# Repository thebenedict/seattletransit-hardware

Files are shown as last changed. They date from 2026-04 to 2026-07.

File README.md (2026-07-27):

# Seattle Transit Live

Schematic and PCB for a circuit board map of Seattle area public transit.

[www.seattletransitlive.com](https://www.seattletransitlive.com/)

This board uses an `ESP32-C3` to drive `383` individually addressable `WS2812` LEDs arranged as a stylized regional transit map. The LEDs are split across two chains, and represent live movement across rail, ferry, water taxi, and monorail routes.

## Main Functionality

- Displays a physical transit map with addressable LEDs placed along the network.
- Uses an `ESP32-C3-MINI-1` as the main controller.
- Takes power and USB data over `USB-C`.
- Drives the LED chains through level shifting and a switchable LED power rail.
- Includes an ambient light sensor for auto-dimming in software.

## Repo Contents

- `transit.kicad_sch`, `transit.kicad_pcb`, and the sub-sheet `.kicad_sch` files contain the Rev C schematic and PCB layout.
- `production/` contains fabrication outputs, BOM data, positions, and packaged manufacturing files.
- `tools/` contains scripts and transit GIS/GTFS inputs used to generate LED map configuration data.
- `3d_views/` and `web/public/` contain renders and SVG exports of the board.

## More soon

- Board firmware and supporting cloud service to be published separately.

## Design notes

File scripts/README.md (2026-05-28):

# Route Placement Scripts

## One-Line Route Placer

`place_route.py` places one line of WS2812B-2020 point LEDs along an existing
silkscreen route. On apply, it rewrites that silkscreen group with filleted
bends. It does not move WS2812B-MINI ferryport LEDs.

Draw the route as F.Silkscreen graphic line segments, group the segments for
one route, and name the group `route:<route_name>`, for example
`route:mukilteo_clinton`. A single straight route can be one grouped line
segment. For this first pass, draw source paths with line segments. After the
script fillets a group, reruns can still read the filleted line/arc pieces for
placement and will leave the existing filleted silk unchanged by default.

Routes can specify either explicit refs or a schematic sheet name:

```json
{
  "routes": {
    "mukilteo_clinton": {
      "silkscreen_group": "route:mukilteo_clinton",
      "schematic": "mukilteo_clinton"
    },
    "example_by_refs": {
      "silkscreen_group": "route:example_by_refs",
      "refs": "LED509-LED512"
    }
  }
}
```

When you pass `--route <route_name>` and that route is not present in the
config, `place_route.py` uses the same simple convention by default:
`silkscreen_group` becomes `route:<route_name>` and `schematic` becomes
`<route_name>`. This lets a config file act as defaults plus a few route
overrides.

When `schematic` is used, the script places all WS2812B-2020 point LED
footprints whose board sheet file or sheet name matches that value. MINI
ferryport LEDs in that schematic are skipped.

Run a dry run with KiCad's bundled Python:

```sh
/Applications/KiCad/KiCad.app/Contents/Frameworks/Python.framework/Versions/3.9/bin/python3.9 \
  scripts/place_route.py \
  --board transit.kicad_pcb \
  --config scripts/place_route.example.json \
  --route mukilteo_clinton
```

Add `--apply` to write the board. `silk_fillet_radius_mm` defaults to `4.0`;
set it per route or in `defaults`, or set it to `0` for sharp corners.
`silk_width_mm` defaults to `0.2`. Set `generate_silk: false` if you want a
route run to leave the grouped silkscreen untouched. If you intentionally want
to rewrite an already-filleted group, set `refillet_existing_silk: true`, but
the cleanest source remains straight segments. Use `reverse_path: true` when
the computed placement order is opposite the route direction you want, and
`reverse_refs: true` when the footprint order should run the other way along
the same path. For one-off runs, the same settings can be passed as
`--reverse-path` / `--no-reverse-path` and `--reverse-refs` /
`--no-reverse-refs`; CLI values override the config for the selected routes.

## Directional Two-Line Route Placer

`place_routes.py` places directional route LEDs and regenerates parallel route
silkscreen from construction lines drawn in KiCad.

## Station Decoration Generator

`stationgen` generates decorative station silkscreen from
`scripts/station_decorations.yaml`. It is intentionally scoped to generated
graphics: standard plain labels, rounded transfer rectangles, and terminal
knockout label pills. It does not move or own LED footprints.

Use the `Capture Selected Station to Config` KiCad IPC action to add stations
from selected LED footprints without typing reference designators. The visible
KiCad menu entry is a small legacy Action Plugin launcher that delegates to the
IPC implementation. See
`docs/stationgen.md` for the KiCad IPC plugin setup, capture workflow, and
config shape.

## Drawing Workflow

1. Use the `Route construction` layer.
2. Draw each route centerline with graphic line segments only. Bends are fine,
   but each segment should be a straight 0/45/90/etc. run. Do not draw arcs on
   the construction layer; the script rounds generated silkscreen bends.
3. Make the segment endpoints touch exactly. Snapping to endpoints/grid is
   recommended.
4. Select all construction segments for one route, group them, and set the
   group name to `route:<route_name>`, for example `route:fauntleroy_vashon`.
5. For a single straight route, duplicate the construction line in place, group
   the two collinear lines, and give that group the route name. The script
   merges overlapping collinear construction lines back into one segment.
6. Add a matching route entry to a JSON config file.

The construction centerline is the midpoint between the two generated
silkscreen lines. With the defaults, the generated silk lines are 4 mm apart,
the two directional LED lines are 4 mm apart, and sequential LED positions are
spaced 5 mm along straight route segments.

Construction endpoints are allowed to be ferry port LED anchors. Non-port ferry
LEDs and generated route silk use the coast-trimmed route path instead. Use
`coast_start_trim_mm` and `coast_end_trim_mm` when the construction line extends
past the coastline to reach a port LED.

## Config Shape

Use `routes.example.json` as a starting point. The simplest route looks like:

```json
{
  "routes": {
    "fauntleroy_vashon": {
      "construction_group": "route:fauntleroy_vashon",
      "refs": "LED526-LED529",
      "endpoints": {
        "start": { "ref": "LED525" },
        "end": { "ref": "LED508" }
      }
    }
  }
}
```

`refs` must be in wiring order. The first half of the refs are placed on the
first direction line from route start to route end. The second half are placed
on the opposite direction line from route end back to route start. This gives a
single data chain of all one-way ferry LEDs followed by all opposite-way ferry
LEDs, with one crossover at the far end. `refs` can be an explicit list, a
range string, or a list that mixes both:

```json
"refs": ["LED526", "LED527", "LED528", "LED529"]
"refs": "LED526-LED529"
"refs": ["LED526-LED529", "LED536", "LED537"]
```

Ranges are inclusive and can use `-` or `..`; `LED526-LED529` and
`LED526..LED529` are equivalent. Ranges can count up or down, so
`LED529-LED526` is valid.
The expanded ref count must be even. By default, the first direction line is on
the left side of the centerline, looking from the route start toward the route
end. Set `"first_direction_side": "right"` on a route to swap that.

`endpoints` can contain one endpoint. Use only `start` or only `end` when a
route reuses a port LED that is owned by another route.

Useful per-route overrides:

- `reverse`: default `true`; the script reverses the ordered construction
  polyline before placing anything. Set to `false` for a route whose
  construction traversal already runs from electrical start to electrical end.
- `coast_start_trim_mm` / `coast_end_trim_mm`: trim the construction path back
  to the coastline before placing non-port ferry LEDs or generating silk.
- `coast_clearance_mm`: default `0.0`; clearance from the coast-trimmed route
  ends to the first non-port ferry LED positions. Endpoint port LEDs ignore this
  and stay anchored to construction endpoints.
- `segment_clearance_mm`: default `0.0`; optional clearance at both ends of
  every straight construction segment. Use this only when you want extra spacing
  near bends as well as coasts.
- `merge_collinear_segments`: default `true`; overlapping or touching collinear
  construction lines are treated as one logical segment. Set to `false` when a
  special route needs to address those drawn subsegments by index.
- `led_spacing_along_mm`: default `5.0`.
- `line_spacing_across_mm`: default `4.0`.
- `silk_parallel_gap_mm`: default `4.0`.
- `silk_fillet_radius_mm`: default `4.0`; generated silkscreen bends are
  rounded to this radius when the adjacent segments are long enough.
- `silk_start_trim_mm` / `silk_end_trim_mm`: additionally shorten generated
  silk after coast trimming.
- `endpoint_orientation`: default `along_route`; ferry port endpoint LEDs are
  rotated to follow the endpoint route tangent. Use `perpendicular_to_route`
  only for an intentional exception.
- `endpoint_start_rotation_offset_deg`: default `-90.0`; compensates for the
  LED footprint at the start endpoint so its long visual edge follows the route.
- `endpoint_end_rotation_offset_deg`: default `0.0`; compensates for the LED
  footprint at the end endpoint so its long visual edge follows the route.
- `mirror_led_rotations_for_power`: default `true`; rotates one direction line
  by 180 degrees so the +VLED pads face the center power trunk.
- `led_rotation_offset_deg`: rotate route LEDs relative to the segment tangent.
- `strict_led_count`: default `true`; errors if geometry produces a different
  number of positions than the route has LEDs per direction. Set to `false` for
  best-effort placement: extra positions are ignored, and too few positions
  compress the route spacing so every ref still gets placed.

Per-segment overrides use zero-based segment indexes in the ordered route:

```json
"segments": {
  "0": { "start_clearance_mm": 2.0 },
  "1": { "no_leds": true },
  "2": { "led_count": 1, "center_offset_along_mm": -0.5 }
}
```

Per-LED overrides are the escape hatch for small visual fixes:

```json
"led_overrides": {
  "LED529": {
    "nudge_mm": [0.2, 0.0],
    "rotation_offset_deg": 180
  }
}
```

## Running

Run with KiCad's bundled Python:

```sh
/Applications/KiCad/KiCad.app/Contents/Frameworks/Python.framework/Versions/3.9/bin/python3.9 \
  scripts/place_routes.py \
  --board transit.kicad_pcb \
  --config scripts/routes.json
```

That is a dry run. It prints the ordered segments, computed route LED positions,
endpoint LED positions, and generated silkscreen count.

To write a copy:

```sh
/Applications/KiCad/KiCad.app/Contents/Frameworks/Python.framework/Versions/3.9/bin/python3.9 \
  scripts/place_routes.py \
  --board transit.kicad_pcb \
  --config scripts/routes.json \
  --apply \
  --output /tmp/transit-route-test.kicad_pcb
```

To regenerate only a route's generated silkscreen while leaving all LEDs and
reference visibility alone:

```sh
/Applications/KiCad/KiCad.app/Contents/Frameworks/Python.framework/Versions/3.9/bin/python3.9 \
  scripts/place_routes.py \
  --board transit.kicad_pcb \
  --config scripts/routes.json \
  --route mukilteo_clinton \
  --apply \
  --silk-only
```

To update the project board in place, close the PCB in KiCad first, then run:

```sh
/Applications/KiCad/KiCad.app/Contents/Frameworks/Python.framework/Versions/3.9/bin/python3.9 \
  scripts/place_routes.py \
  --board transit.kicad_pcb \
  --config scripts/routes.json \
  --apply
```

Generated silkscreen lines and fillet arcs are grouped as
`routegen:<route_name>`. Rerunning the script deletes and recreates that group,
so manual edits inside generated groups will not be preserved.

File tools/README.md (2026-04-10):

# LED Map Generation Pipeline

Generates `rev-a.json` (the board config) from KiCad source files and GTFS data.

## Required Input Files

### From KiCad project (you provide):
```
kicad/
├── transit.kicad_sch          # Main schematic (for reference)
├── rail_w.kicad_sch           # Rail West chain (106 LEDs, part 1)
├── rail_w_southbound.kicad_sch # Rail West chain (part 2, continues from rail_w)
├── rail_e.kicad_sch           # Rail East chain (48 LEDs)
├── ferries_n.kicad_sch        # Ferries North chain (46 LEDs)
├── ferries_s.kicad_sch        # Ferries South chain (47 LEDs)
└── transit.kicad_pcb          # PCB layout (for LED physical positions)
```

### From GTFS / transit agencies (downloaded):
- Sound Transit GTFS `stops.txt` and `shapes.txt`
- WSF terminal coordinates
- KC Water Taxi stop coordinates

### Hand-maintained:
- `station_labels.csv` — maps LED reference designators to station names and GTFS stop IDs

## Pipeline Steps

### Step 1: `01_extract_chain_order.py`
**Input:** KiCad `.kicad_sch` files (sub-sheets)
**Output:** `chain_order.json`

Parses schematic wiring to determine LED daisy-chain order per chain.
Traces DO→DI pin connections through wires.

```bash
python 01_extract_chain_order.py /path/to/kicad/
```

### Step 2: `02_extract_pcb_positions.py` (TODO)
**Input:** `transit.kicad_pcb`
**Output:** `pcb_positions.json`

Extracts board-space (x, y) position of every LED footprint from the PCB layout.

### Step 3: `03_merge_leds.py` (TODO)
**Input:** `chain_order.json` + `pcb_positions.json`
**Output:** `leds_merged.json`

Joins chain order with PCB positions. Assigns global indices. Validates 247 total.

### Step 4: `04_assign_stations.py` (TODO)
**Input:** `leds_merged.json` + `station_labels.csv` + GTFS data
**Output:** `leds_with_geo.json`

Enriches LEDs with station labels and geographic coordinates (lat/lng).

### Step 5: `05_build_routes.py` (TODO)
**Input:** `leds_with_geo.json` + GTFS shapes + route definitions
**Output:** `routes.json`

Constructs route objects with geoPath, ledIndices, ledProgress,
and progressThresholds. Handles shared LEDs across routes.

### Step 6: `06_assemble_rev_a.py` (TODO)
**Input:** `leds_with_geo.json` + `routes.json`
**Output:** `rev-a.json`

Assembles the final board config JSON with all sections.

### Step 7: `07_validate.py` (TODO)
**Input:** `rev-a.json`
**Output:** Validation report + visual overlay PNG

Comprehensive validation suite.

## Shared LED Handling

Three LEDs are shared across routes:

1. **Seattle water taxi terminal** — shared by Seattle–West Seattle WT and Seattle–Vashon WT
2. **First waypoint after Seattle terminal** — same two routes share their first leg
3. **Vashon triangle crossing** — Seattle–Vashon WT crosses Fauntleroy–Southworth WSF

These appear in multiple routes' `ledIndices` arrays but only once in the `leds` array.
Collision policy: last-writer-wins (active vessel takes priority).

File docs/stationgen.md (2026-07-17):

# StationGen

StationGen generates disposable silkscreen decoration for named stop groups.
LED footprints remain owned by the board and existing placement tools; StationGen
only owns generated graphics in groups named `stationgen:<station_id>`.

## Current Scope

- Transfer stations: rounded rectangle generated from the union of LED footprint
  bounding boxes, expanded by a style padding token. Rectangles may also use
  `decoration.angle_deg` for angled transfer groups.
- Standard stations: plain generated label text, with no station decoration.
- Ferry ports: plain generated label text, with no station decoration, using a
  larger label anchor radius for the WS2812B Mini footprint.
- Terminal stations: filled graphical-zone label pill plus knockout text. The
  zone fill is what lets KiCad's knockout text cut through the silkscreen fill.
- Labels: side-based placement around the station decoration/core with explicit
  `angle_deg`, `offset_mm`, alignment, and optional `position_mm` / `nudge_mm`
  exceptions.

No ferry-only terminal decoration is implemented yet.

## Config

The project config is [`scripts/station_decorations.yaml`](../scripts/station_decorations.yaml).
Styles define shared tokens; stations define intent:

```yaml
stations:
  intl_district_chinatown:
    class: standard
    refs: [LED1727, LED1827]
    label:
      text: |-
        Intl. District
        Chinatown
      align: left
      side: E

  mukilteo:
    class: transfer
    refs: [LED1101, LED1409, LED1421]
    label:
      text: Mukilteo
      align: auto
      side: NW
      offset_mm: 0.80

  vashon_island:
    class: ferry_port
    refs: [LED401]
    label:
      text: Vashon Island
      side: SW
      align: right
      align_x: right
      angle_deg: 45.0

  westlake:
    class: transfer
    refs: [LED1601, LED1733, LED1821]
    decoration:
      angle_deg: 315.0
```

Label positions use compass sides: `N`, `NE`, `E`, `SE`, `S`, `SW`, `W`,
`NW`, or `C`. `offset_mm` is projected clearance from the station geometry to
the rendered label geometry in that compass direction, so angled labels and
horizontal labels use the same spacing rule. Labels with `anchor_radius_mm`
configured and no generated decoration anchor against a style-controlled halo
around each selected LED center. This avoids rotated footprint bounding boxes
creating larger apparent gaps. Tune `anchor_radius_mm` on the applicable label
style if that station class needs to move in or out. Transfer labels anchor
against the generated rounded rectangle. Plain labels default to `align: auto`, which left-aligns
east-side labels, right-aligns west-side labels, and centers north/south labels
so text grows away from the station. Knockout pill labels default to centered
text.
Use YAML literal blocks for multiline labels; StationGen also normalizes KiCad
captured carriage returns to normal newline characters. Multiline generated text
defaults to KiCad `line_spacing: 1.0`; override `label.line_spacing` only when a
specific label needs tighter or looser leading.
Use `align_x: left|center|right` or `align_y: top|center|bottom` when a label
should keep a side placement but align one measured label edge with the station
decoration edge. For example, `side: N` plus `align_x: left` puts the label above
the station while aligning its left edge to the rectangle's left edge.
Use `cross_align: top|bottom|left|right|min|center|max` when the label should
stay on the requested side, but its centerline should align with a different
part of the station anchor along the cross axis. For example, `side: E` plus
`cross_align: top` keeps the label east of a diagonal LED pair while lining it
up with the upper LED instead of centering it between both LEDs.
For angled transfer boxes, set `decoration.angle_deg`; StationGen measures the
station content in that rotated coordinate system, applies the normal
`padding_mm`, and then generates a polygonal rounded rectangle on silkscreen.
Angled boxes use `decoration.content_radius_mm` as the visual radius around each
selected LED center before padding, which keeps diagonal groups from inheriting
oversized screen-aligned footprint bounding boxes. Labels for transfer stations
anchor against the generated rotated outline.

Stations can define internal `sublabels` for special cases like Seattle's
`Pier 50` and `Pier 52` labels. Sublabel text boxes are included in the
station's rounded-rectangle content box before normal decoration padding is
applied, and the sublabel text is generated inside the station group:

```yaml
stations:
  seattle:
    class: transfer
    refs: [LED701, LED515]
    sublabel_defaults:
      align: center
      vertical_align: center
      size_mm: 1.00
      stroke_mm: 0.15
    sublabels:
      - text: Pier 52
        position_mm: [125.77, 52.80]
      - text: Pier 50
        position_mm: [125.77, 60.80]
```

## KiCad Plugin

The repo-local plugin lives in [`stationgen`](../stationgen). This is an IPC API
plugin, not a legacy `pcbnew` action plugin, so it belongs in KiCad's versioned
`plugins` directory, not `scripting/plugins`:

```sh
mkdir -p /Users/michael/Documents/KiCad/10.0/plugins
rm -f /Users/michael/Documents/KiCad/10.0/plugins/stationgen
ln -s /Users/michael/Documents/transit/stationgen \
  /Users/michael/Documents/KiCad/10.0/plugins/stationgen
```

KiCad will create the plugin Python environment and install
[`stationgen/requirements.txt`](../stationgen/requirements.txt). KiCad's
visible PCB Editor menu still scans the legacy scripting plugin folder, so this
project also installs a small legacy Action Plugin launcher at:

```sh
/Users/michael/Documents/KiCad/10.0/scripting/plugins/stationgen_legacy_action_plugin.py
```

That launcher delegates to the IPC implementation. Use the PCB editor actions
under `Tools -> External Plugins`:

- `Regenerate Station Decorations`: delete and recreate generated decoration
  groups from the YAML config.
- `Capture Selected Station to Config`: create or update one station entry from
  the current selection.

On this Mac, these menu actions are also assigned as KiCad app shortcuts:

- `Cmd+Option+R`: `Regenerate Station Decorations`
- `Cmd+Option+C`: `Capture Selected Station to Config`

Make sure KiCad's IPC API is enabled first: KiCad -> Settings... -> Plugins ->
Enable KiCad API. Restart KiCad after adding the symlink. The action should then
appear in the PCB Editor as `Regenerate Station Decorations`; the first load may
take a little while while KiCad builds the plugin Python environment. If the
menu only shows `Refresh Plugins` and `Reveal Plugin Folder in Finder`, click
`Refresh Plugins`. That menu's reveal command opens
`/Users/michael/Documents/KiCad/10.0/scripting/plugins`, not the IPC plugin
folder.

If KiCad creates the plugin environment but does not show the action in the UI,
leave the board open and run StationGen directly through the KiCad-created
environment:

```sh
cd /Users/michael/Documents/transit
/Users/michael/Library/Caches/KiCad/10.0/python-environments/com.charlesstreetlabs.stationgen/bin/python \
  -m stationgen --config scripts/station_decorations.yaml
```

To add another station without typing LED reference designators, select the
station's LED footprints in the PCB editor. Optionally select one existing free
text label too; StationGen will use it as the default label text, label angle,
and side hint. Plain selected text defaults to the `standard` class; knockout
selected text defaults to `terminal`; selecting only footprints defaults to
`transfer`. Then run `Capture Selected Station to Config`. The dialog lets you
choose the station id, `standard`, `ferry_port`, `transfer`, or `terminal`, side
placement, text alignment, optional edge/cross alignment, and whether to
regenerate that station immediately. After a successful capture, StationGen
removes the selected source text label from the board so the generated label is
the only copy.

The same capture workflow can run from the terminal while the board is open:

```sh
cd /Users/michael/Documents/transit
/Users/michael/Library/Caches/KiCad/10.0/python-environments/com.charlesstreetlabs.stationgen/bin/python \
  -m stationgen \
  --config scripts/station_decorations.yaml \
  --capture-selected
```

For a non-dialog capture, pass the needed options explicitly:

```sh
/Users/michael/Library/Caches/KiCad/10.0/python-environments/com.charlesstreetlabs.stationgen/bin/python \
  -m stationgen \
  --config scripts/station_decorations.yaml \
  --capture-selected \
  --capture-no-dialog \
  --station-id northgate \
  --station-class transfer \
  --label-text Northgate \
  --label-side E \
  --label-align auto \
  --label-cross-align top \
  --regenerate-after-capture
```

Terminal knockout labels trigger a KiCad zone refill. If KiCad remains busy
longer than the IPC wait loop, StationGen may print a warning but the refill can
still finish in KiCad; wait for the board to become responsive before saving.

Do not create a `stationgen` symlink inside the repo's own
`/Users/michael/Documents/transit/stationgen` directory. KiCad 10.0.1 traverses
plugin folders recursively during startup, and a recursive symlink can crash
KiCad during plugin discovery.

StationGen only deletes and recreates groups with the configured generated
prefix. Existing hand-drawn silkscreen labels and rectangles are left alone, so
delete or move those manually as stations are migrated into the YAML config.

For command-line config validation:

```sh
python -m pip install -r stationgen/requirements.txt
python -m stationgen --config scripts/station_decorations.yaml --check-config
```

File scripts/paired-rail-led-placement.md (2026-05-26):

# Paired Rail LED Placement

This note describes the manual PCB transform used for the Sounder and Tacoma
paired LED rails. It is scriptable because each partner footprint is derived
from its already-placed mate with a fixed geometric rule.

## Inputs

- KiCad board file: `transit.kicad_pcb`
- Sheet path, for example `/Rail/sounder_s/`, `/Rail/sounder_n/`, or
  `/Rail/tacoma_t/`
- First group refs in track order, for example `LED1501` through `LED1512`
- Partner group refs in matching order, for example `LED1513` through
  `LED1524`
- Pair spacing: `4.0 mm`

The schematic should already contain the correct sequential electrical chain
for both groups. If the partner refs are out of order, fix the refs/net chain
first, then apply the geometry transform.

## PCB Parsing

Parse `transit.kicad_pcb` as balanced S-expressions, not line-by-line text.
For this task it is enough to split top-level `(footprint ...)` forms while
respecting quoted strings.

Select only footprints with:

```scheme
(sheetname "/Rail/<sheet_name>/")
```

Then read:

- reference from `(property "Reference" "LED1501" ...)`
- symbol path from `(path ".../<symbol_uuid>")`
- top-level footprint placement from the first footprint-level `(at x y rot)`
- pad nets from pads whose `pinfunction` is `DI_3` or `DO_1`

## Pair Geometry

For each pair:

```text
source_ref  = LED1501 + i
partner_ref = LED1513 + i
```

Read the source footprint center and rotation:

```text
x, y, theta_deg
```

Compute the partner center using the same 4 mm normal offset convention used on
the board:

```text
dx = 4.0 * cos(theta_deg)
dy = -4.0 * sin(theta_deg)

partner_x = x + dx
partner_y = y + dy
partner_rotation = theta_deg + 180
```

Normalize rotation only for presentation if desired. KiCad accepts equivalent
angles such as `-45`, `315`, or `135`; consistency matters more than the exact
range.

Examples:

```text
theta -45  -> offset (+2.828427, +2.828427), partner rotation 135
theta -90  -> offset (0, +4), partner rotation 90
theta -135 -> offset (-2.828427, +2.828427), partner rotation 45
theta 180  -> offset (-4, 0), partner rotation 0
```

This puts the partner footprint on the parallel silkscreen rail and rotates it
to face the opposite travel direction.

## PCB Rewrite

For every partner footprint:

1. Replace the top-level footprint `(at x y rot)` with the computed partner
   placement.
2. Update nested `(at local_x local_y rot)` rotations inside that same
   footprint to the computed partner rotation. This includes reference/value
   fields, user text, and pads.
3. Do not change the footprint UUID, schematic path, reference, pad nets, or
   any unrelated footprint.

The source group footprints are read-only inputs for this operation.

## Sequential Ref Repair

If geometry is correct but partner refs run out of order, derive the actual
chain from the PCB nets:

1. Build a map from each partner footprint's `DI_3` net to its reference.
2. For each partner footprint, map its `DO_1` net to the next footprint whose
   `DI_3` uses that net.
3. Walk from the first partner ref whose `DI_3` is unconnected or externally
   sourced.
4. Rename that walked order to the desired sequential refs.

When applying a ref permutation, use temporary placeholders so names do not
collide:

```text
LED1328 -> __TMP_01__ -> LED1326
```

Apply the same ref permutation to:

- schematic symbol `Reference` properties
- schematic instance references
- PCB footprint `Reference` properties
- PCB net names such as `Net-(LED1328-DO)`
- unconnected net names such as `unconnected-(LED1328-DI-Pad3)`

After renaming, keep symbol UUID/path associations intact. If moving logical
footprints to different physical slots, transplant only the `(at ...)` values
from the destination slot to the logical footprint.

## Validation

After rewriting the PCB, verify all of these before opening KiCad:

1. Every expected source and partner ref exists exactly once on the target
   sheet.
2. For each pair:

   ```text
   hypot(partner_x - source_x, partner_y - source_y) == 4.000000
   (partner_rotation - source_rotation) mod 360 == 180
   ```

3. The partner chain is sequential:

   ```text
   LED1513 -> LED1514 -> ... -> LED1524
   ```

   Derive this from `DO_1` to `DI_3` nets, not from footprint order in the file.

4. PCB footprint paths still match schematic symbol UUIDs for the sheet.
5. Run:

   ```sh
   git diff --check -- transit.kicad_pcb
   ```

## Minimal Script Shape

A future script can expose this as:

```sh
python scripts/place_paired_rail_leds.py \
  --board transit.kicad_pcb \
  --sheet /Rail/tacoma_t/ \
  --source LED1501-LED1512 \
  --partners LED1513-LED1524 \
  --spacing-mm 4.0 \
  --apply
```

The script should default to a dry run that prints the computed placements and
the validation table before writing the board.

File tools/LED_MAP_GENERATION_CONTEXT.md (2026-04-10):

# Transit Tracker — LED Map Generation: Context & Instructions

This document provides full context for generating `led-maps/rev-a.json`, the board configuration file that maps real-world geographic coordinates to LED indices on a physical transit display board.

Read this document fully before starting work.

## Project Summary

The Transit Tracker is a physical PCB with 247 individually addressable WS2812B LEDs arranged on a stylized transit map of the Puget Sound region. A cloud service polls transit APIs for real-time vehicle positions (lat/lng), maps each position to the nearest LED, and streams color updates to the board over SSE.

The full design document is at `transit-tracker-design.md`. Read it for the SSE protocol, firmware architecture, and web frontend details — but for this task, only the LED map JSON schema (§6) matters.

## The Core Problem

The board's map is **stylized** (like a subway diagram), not geographic. There is no affine transform from lat/lng to board space. We need a data file that lets the server answer: "A vehicle is at lat/lng X on route Y — which LED do I light up?" in effectively constant time.

## The Solution: Route-Progress Based Lookup

Each route is modeled as a progress bar from 0.0 to 1.0 along its real-world geographic polyline:

1. Server receives vehicle position (lat/lng) + route ID + direction from API
2. Project lat/lng onto the route's real-world geoPath polyline → scalar progress (0.0–1.0)
3. Find nearest value in `ledProgress` → LED index

The polyline projection uses standard point-to-polyline snapping: for each segment of the polyline, compute the perpendicular projection, clamp to segment bounds, find the nearest segment, and compute progress as cumulative distance to that point divided by total polyline length. At Puget Sound latitudes (~47.5°N), use a local Cartesian approximation (scale longitude by cos(47.5°)) — Earth curvature error is negligible at city scale.

For the runtime server (Node.js), Turf.js `nearestPointOnLine()` does this in one call. For offline generation (Python), Shapely `line.project(point, normalized=True)` does it.

## Ferry vs Rail: Direction Handling

**Ferry routes** use a single line of LEDs for both directions. A ferry at the midpoint of a crossing lights the same LED regardless of heading. The server ignores direction — it just projects lat/lng onto the route's geoPath. One route object per ferry route.

**Rail routes** have separate LED strips per direction (northbound LEDs are physically different from southbound LEDs on the board). The server uses the trip direction from the API to select the correct route object. Two route objects per rail line (one per direction). Both geoPath polylines follow the same physical track, just in opposite directions.

## Input Data

### 1. Transit_stops__LEDs.csv (in project root)

**This is the primary data source.** A manually created file mapping every LED to its route(s), chain position, and station label. 307 rows, 9 columns:

- **Type**: "Light rail", "Ferry", "Monorail", "Taxi"
- **Chain**: "Rail W", "Rail E", "Ferries N", "Ferries S"  
- **REF**: LED reference designator, e.g. "LED201"
- **Route**: Route identifier — "1" (Line 1), "2" (Line 2), "sea-br" (Seattle-Bremerton), "sea-bi" (Seattle-Bainbridge), "ed-king" (Edmonds-Kingston), "pd-tal" (Point Defiance-Tahlequah), "s-v" (Southworth-Vashon), "f-s" (Fauntleroy-Southworth), "f-v-s" (Fauntleroy-Vashon-Southworth triangle), "taxi-vashon" (Seattle-Vashon water taxi), "taxi-west-seattle" (Seattle-West Seattle water taxi), "monorail"
- **Direction**: "Northbound", "Southbound", "Eastbound", "Westbound", or empty (ferries)
- **Order in route**: 0-indexed position within that route
- **Order in chain**: 0-indexed position within the physical LED chain
- **Label**: Station/terminal name (empty for waypoint LEDs between stations)
- **Note**: Annotations about shared LEDs, skipped designators, etc.

Key structural patterns:
- Station LEDs and waypoint LEDs alternate: every other LED has a label
- LEDs appearing in multiple rows are **shared LEDs** (same physical LED, multiple routes)
- Rail W chain (106 LEDs): LED201-LED253 (northbound) + LED601-LED653 (southbound, separate sub-sheet)
- Rail E chain (48 LEDs): LED301-LED348
- Ferries N chain (46 LEDs): LED401-LED447 (LED430 was skipped due to schematic error)
- Ferries S chain (47 LEDs): LED501-LED547

### 2. GIS Route Polylines (in gis-data/)

These provide the real-world geographic paths for each route:

- **`gis-data/wsdot-ferry-routes.geojson`** — WSF ferry route polylines from WSDOT GIS portal. GeoJSON LineString features with route name attributes. Covers all WSF routes (sea-br, sea-bi, ed-king, pd-tal, s-v, f-s, f-v-s).

- **`gis-data/sound-transit-gtfs/`** — Unzipped Sound Transit GTFS (from `https://www.soundtransit.org/GTFS-rail/40_gtfs.zip`). Contains `shapes.txt` (route polylines), `stops.txt` (station lat/lng), `routes.txt`, `trips.txt`. Covers Link Lines 1 and 2.

- **`gis-data/kcm-gtfs/`** — Unzipped King County Metro GTFS (from `https://www.soundtransit.org/GTFS-KCM/google_transit.zip`). Contains water taxi route shapes and stops. Covers taxi-vashon and taxi-west-seattle.

- **`gis-data/monorail-gtfs/`** — Unzipped Seattle Monorail GTFS (from `https://gtfs.sound.obaweb.org/prod/96_gtfs.zip`). Covers the monorail route.

### 3. Ferry_Routes.geojson (in project root)

May contain the same or similar ferry route data as the WSDOT download. Check and use if present.

## Shared LEDs

These physical LEDs appear in multiple routes. They appear as multiple rows in the CSV with the same REF but different Route values:

1. **LED513** (Southworth) — routes `s-v` and `f-s`
2. **LED525** (Fauntleroy) — routes `f-s` and `f-v-s`  
3. **LED508** (Vashon Island) — routes `s-v`, `f-v-s`, and `taxi-vashon`
4. **LED518** — crossing point where `taxi-vashon` crosses `f-s` (noted "Crosses f-s, shared LED")
5. **LED543** — shared by `taxi-vashon` and `taxi-west-seattle` (Seattle terminal area)
6. **LED601–LED627** on Rail W — shared by Line 1 southbound and Line 2 eastbound (the downtown overlap section, Lynnwood to Intl District)
7. **LED227–LED253** on Rail W — shared by Line 1 northbound and Line 2 westbound

Collision policy: last-writer-wins. When two vehicles on different routes map to the same LED, the most recently processed one determines the color. No blending needed.

## Output: rev-a.json Schema

```jsonc
{
  "boardRevision": "A",
  "totalLeds": 247,
  
  "chains": {
    "rail_w":    { "gpio": 10, "count": 106 },
    "rail_e":    { "gpio": 1,  "count": 48 },
    "ferries_n": { "gpio": 5,  "count": 46 },
    "ferries_s": { "gpio": 4,  "count": 47 }
  },

  "gpios": {
    "vled_en":      { "gpio": 6, "active_high": true },
    "lvl_shift_en": { "gpio": 7, "active_high": false },
    "wifi_led":     { "gpio": 0, "active_high": true }
  },

  "leds": [
    {
      "index": 0,                    // global LED index (0..246)
      "chain": "rail_w",             // which physical chain
      "chainIndex": 0,               // position within chain (0-indexed)
      "ref": "LED201",               // schematic reference designator
      "label": "Federal Way Downtown", // station name, or null for waypoints
      "type": "station",             // "station" | "terminal" | "waypoint"
      "package": "2020"              // "2020" (WS2812B-2020) or "mini" (WS2812B-MINI)
    }
    // ... 247 entries total
  ],

  "routes": [
    {
      "id": "link-1-northbound",
      "type": "rail",                // "rail" | "ferry" | "monorail" | "water_taxi"
      "operator": "sound_transit",
      "line": "1",                   // matches Route column in CSV
      "direction": "northbound",     // null for ferries
      "defaultColor": { "r": 0, "g": 200, "b": 0 },

      // Ordered LED indices for this route (references into leds[])
      "ledIndices": [0, 1, 2, ...],

      // Real-world route polyline (from GTFS/GIS)
      "geoPath": [[47.3174, -122.3032], [47.3180, -122.3030], ...],

      // Progress value (0.0-1.0) along geoPath for each LED
      // Same length as ledIndices
      "ledProgress": [0.0, 0.019, 0.038, ...]
    }
  ],

  "sharedLeds": [
    {
      "ledIndex": 42,               // global index
      "ref": "LED513",
      "routes": ["southworth-vashon", "fauntleroy-southworth"],
      "note": "Southworth terminal"
    }
  ],

  "collisionPolicy": "last_writer_wins"
}
```

### Important notes about the schema:

- `leds[].index` is the global index (0-246). The mapping from global index to chain is deterministic: rail_w = 0..105, rail_e = 106..153, ferries_n = 154..199, ferries_s = 200..246. The `chainIndex` field gives the position within the chain.

- `leds[]` does not contain geographic coordinates. All geographic data lives in `routes[].geoPath` and `routes[].ledProgress`. The leds array is purely about physical board identity (chain, index, ref, label, package).

- `routes[].geoPath` is `[lat, lng]` pairs (not `[lng, lat]` — match the GTFS convention).

- `routes[].ledIndices` references global LED indices, not chain indices. A route can span chains (Line 2 spans rail_w and rail_e).

- `routes[].ledProgress` — for station LEDs, computed by projecting the GTFS stop coordinate onto the route's geoPath. For waypoint LEDs (unlabeled, between stations), interpolated evenly between the flanking stations' progress values.

- At runtime, the server finds the nearest LED by binary-searching `ledProgress` for the vehicle's progress value, then comparing the two neighboring entries to find the closest. No precomputed thresholds needed.

- Ferry routes have `"direction": null`. Rail routes always have a direction.

- The `package` field: the 13 ferry terminal LEDs use "mini" (WS2812B-MINI, larger package). All others use "2020". The terminals are the labeled endpoints of ferry routes (Seattle, Bainbridge Island, Bremerton, Kingston, Edmonds, Fauntleroy, Vashon Island, Southworth, Point Defiance, Tahlequah, West Seattle) plus the two water taxi Seattle terminals. Determine which are "mini" from the CSV labels at chain endpoints.

## What to Build

A Python script (or small set of scripts) that:

1. **Parses the CSV** to extract chain order, route definitions, station labels, and shared LED relationships.

2. **Reads GIS data** (GeoJSON for ferries, GTFS shapes.txt/stops.txt for rail/monorail/water taxi) to get route polylines and station coordinates.

3. **Matches stations to GTFS stops** — the CSV `Label` values need to be matched to GTFS `stop_name` values to get lat/lng. This may require fuzzy matching (e.g., "SeaTac / Airport" vs "SeaTac/Airport Station"). Log any unmatched stations for manual review.

4. **Builds geoPath for each route** — for rail, extract the GTFS shape polyline for the correct route+direction. For ferries, extract the matching route from the ferry GeoJSON. For routes spanning multiple chains (Line 2), concatenate the geoPath segments.

5. **Computes ledProgress** — project each station LED's GTFS stop coordinate onto its route's geoPath to get its progress value. Interpolate waypoint LEDs evenly between flanking stations.

6. **Assembles and writes rev-a.json** — combining all the above into the schema described.

7. **Validates** — check LED count (247), chain sizes (106, 48, 46, 47), route continuity, progress monotonicity, geographic plausibility (station lat/lng from GTFS within Puget Sound bounding box ~47.0-48.0 lat, -123.0 to -122.0 lng).

### Handling GTFS shapes.txt

GTFS `shapes.txt` format:
```
shape_id,shape_pt_lat,shape_pt_lon,shape_pt_sequence,shape_dist_traveled
```

To find the right shape_id for a given route+direction:
1. In `routes.txt`, find the `route_id` for the line (filter by `route_short_name` or `route_long_name`)
2. In `trips.txt`, find trips for that `route_id` with the desired `direction_id` (0 or 1)
3. Get the `shape_id` from those trips
4. In `shapes.txt`, collect all points for that shape_id, ordered by sequence
5. Convert to a GeoJSON LineString or list of [lat, lng] pairs

### Handling ferry GeoJSON

The WSDOT ferry routes GeoJSON has features with route identification in their properties (likely a `ROUTE_ID` or `ROUTENAME` field). Inspect the file to determine the exact property name, then filter features by route. Each feature's geometry is a LineString of [lng, lat] coordinates (GeoJSON standard is [lng, lat], so swap to [lat, lng] for our schema).

### Route ID Mapping

Map the CSV `Route` values to the GIS data source identifiers:

| CSV Route | Type | GIS Source | Notes |
|---|---|---|---|
| 1 | rail | Sound Transit GTFS | Line 1, both directions |
| 2 | rail | Sound Transit GTFS | Line 2, both directions |
| sea-br | ferry | WSDOT GeoJSON | Seattle-Bremerton |
| sea-bi | ferry | WSDOT GeoJSON | Seattle-Bainbridge |
| ed-king | ferry | WSDOT GeoJSON | Edmonds-Kingston |
| pd-tal | ferry | WSDOT GeoJSON | Point Defiance-Tahlequah |
| s-v | ferry | WSDOT GeoJSON | Southworth-Vashon |
| f-s | ferry | WSDOT GeoJSON | Fauntleroy-Southworth |
| f-v-s | ferry | WSDOT GeoJSON | Fauntleroy-Vashon (triangle leg) |
| taxi-vashon | water_taxi | KCM GTFS | Seattle-Vashon water taxi |
| taxi-west-seattle | water_taxi | KCM GTFS | Seattle-West Seattle water taxi |
| monorail | monorail | Monorail GTFS | Westlake-Seattle Center |

### Color Defaults

| Route type | Color |
|---|---|
| Line 1 | Green: (0, 200, 0) |
| Line 2 | Blue: (0, 80, 255) |
| WSF ferries | White: (255, 255, 255) |
| Water taxis | Turquoise: (0, 220, 200) |
| Monorail | Red: (255, 0, 0) |

## Working Notes

- The CSV has 307 rows but only 247 unique LEDs — the extra rows are shared LEDs appearing in multiple routes.
- LED430 was skipped in the schematic (noted in CSV). The chain goes LED429 → LED431. This doesn't affect anything — just means there's no LED with ref "LED430".
- The `Order in chain` column in the CSV directly gives the `chainIndex` value for each LED.
- The `Order in route` column gives the position within the route's `ledIndices` array.
- For Line 2, the route spans two chains: it starts on Rail W (shared LEDs) then continues on Rail E (or vice versa depending on direction). The `ledIndices` array will contain global indices from both chains.

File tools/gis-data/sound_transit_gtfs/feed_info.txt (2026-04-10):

feed_id,feed_publisher_name,feed_publisher_url,feed_lang,feed_start_date,feed_end_date,feed_version,default_lang,feed_contact_email,feed_contact_url
40,Sound Transit,https://www.soundtransit.org,en,20260202,20260828,SC-Spring-2026.4,en,open_transit_data@soundtransit.org,https://www.soundtransit.org/help-contacts/business-information/open-transit-data-otd

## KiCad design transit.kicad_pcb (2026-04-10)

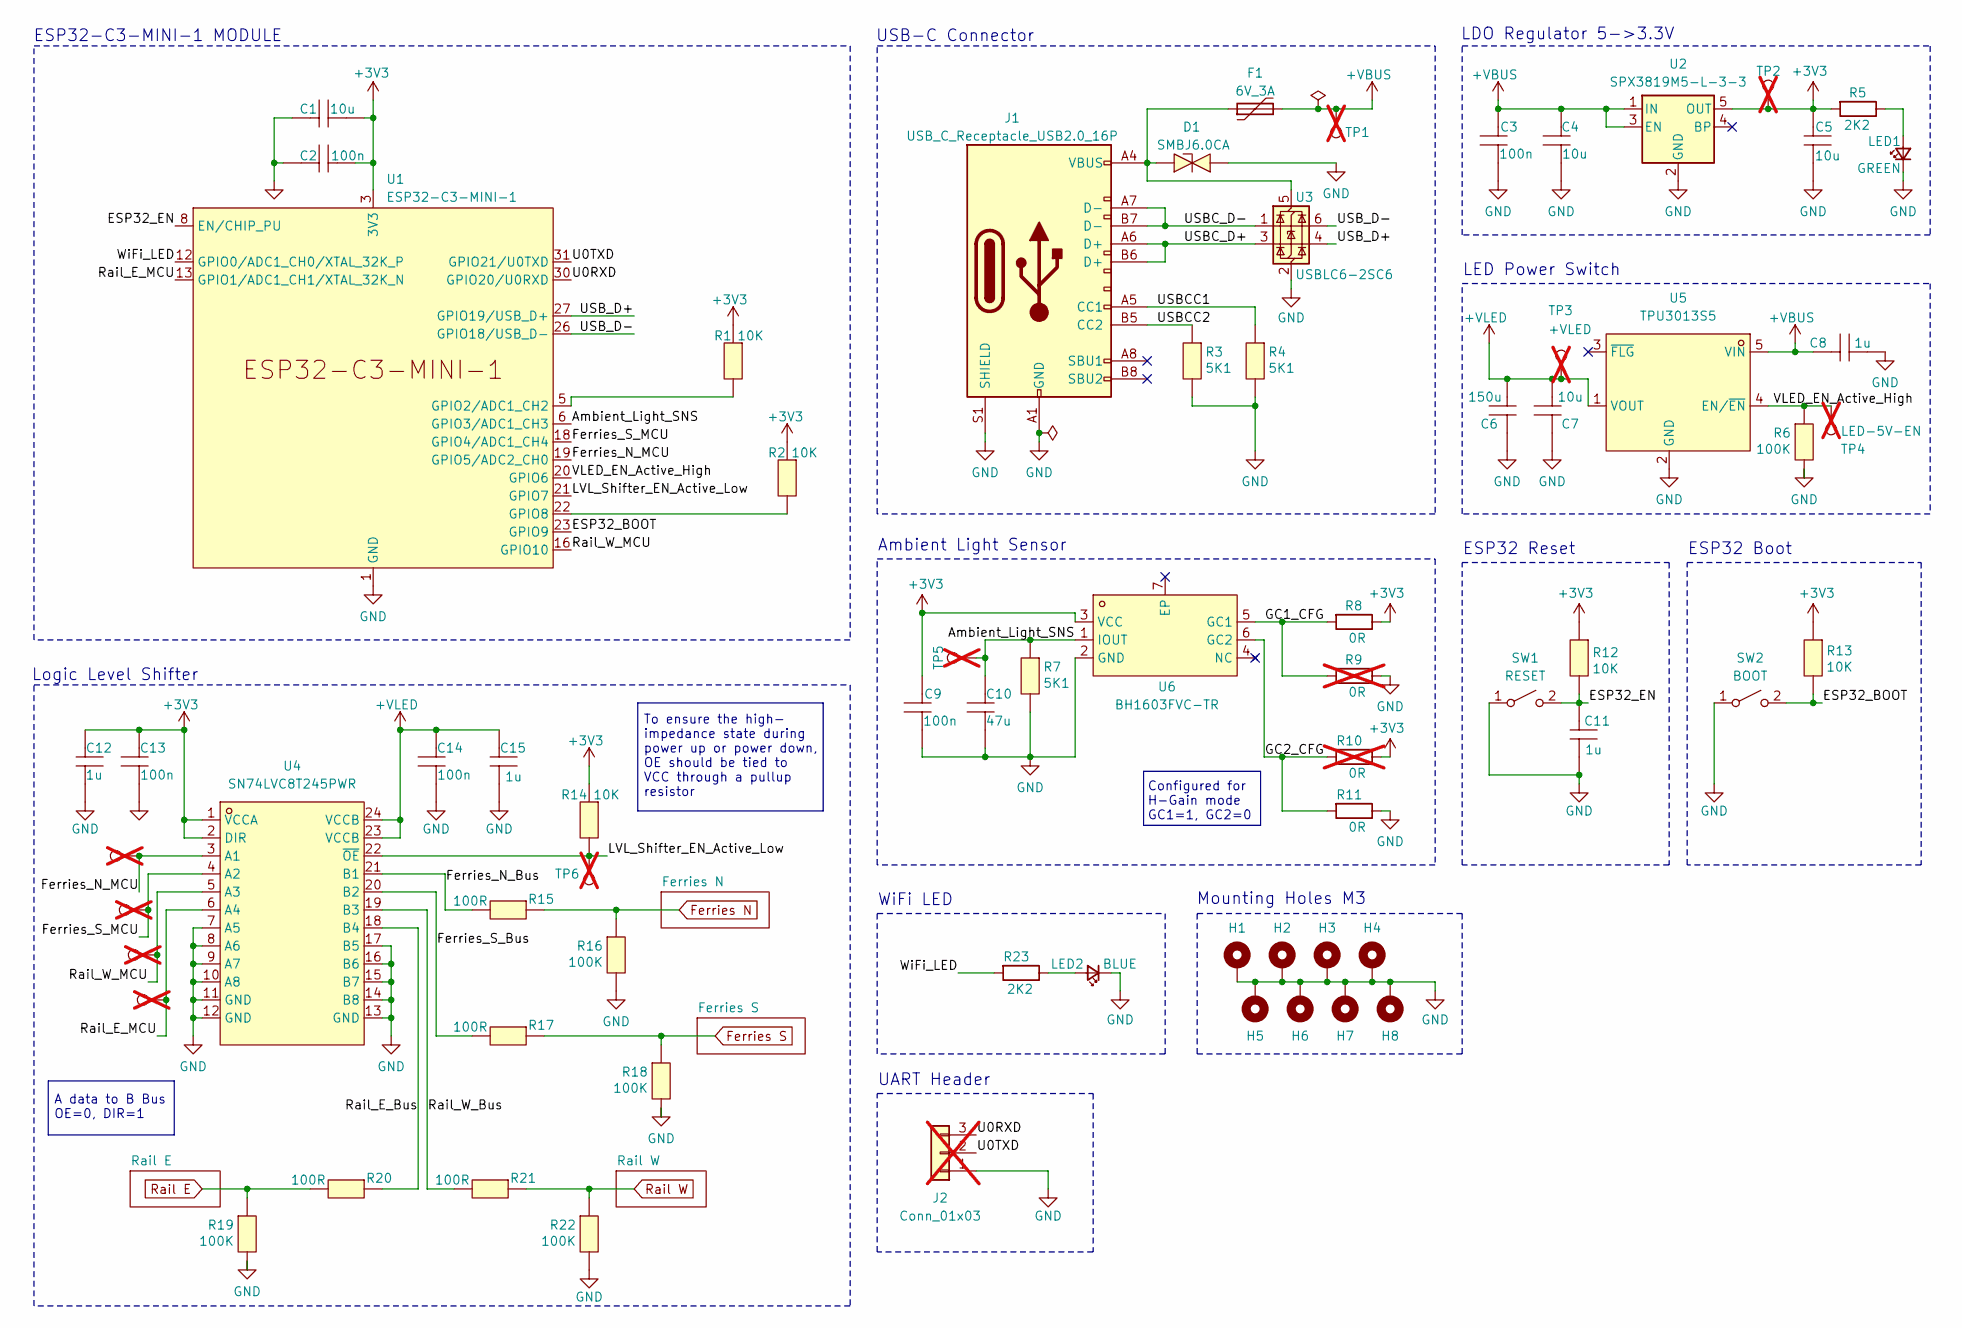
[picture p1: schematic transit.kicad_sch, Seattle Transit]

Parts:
C1, C4, C5, C7: 10u; C0805; LCSC Part C95841
C2, C3, C9, C13, C14: 100n; C0603; LCSC Part C1591
C6: 150u; CAP-SMD_L3.5-W2.8; LCSC Part C212682
C8, C11, C12, C15: 1u; C0603; LCSC Part C15849
C10: 47u; C1206; LCSC Part C96123
D1: SMBJ6.0CA; SMB_L4.3-W3.6-LS5.4-BI; LCSC Part C78812
F1: 6V_3A; F1210; LCSC Part C914223
H1, H2, H3, H4, H5, H6, H7, H8: MountingHole_3.2mm_M3_DIN965_Pad
J1: USB_C_Receptacle_USB2.0_16P; USB_C_Receptacle_GCT_USB4105-xx-A_16P_TopMnt_Horizontal; LCSC C393939
J2: Conn_01x03; PinHeader_1x03_P2.54mm_Vertical; not fitted
LED1: GREEN; LED0805-R-RD; LCSC Part C2297
LED2: BLUE; LED0805-R-RD; LCSC Part C2293
R1, R2, R12, R13, R14: 10K; R0603; LCSC Part C25804
R3, R4, R7: 5K1; R0603; LCSC Part C23186
R5, R23: 2K2; R0603; LCSC C4190
R6, R16, R18, R19, R22: 100K; R0603; LCSC Part C25803
R8, R11: 0R; R0603; LCSC C21189
R9, R10: 0R; R0603; LCSC C21189; not fitted
R15, R17, R20, R21: 100R; R0603; LCSC Part C22775
SW1, SW2: SW_SPST; KEY-SMD_L6.2-W3.6-LS8.0_K2-1107ST-A4SW-06; LCSC Part C118141
TP1: +VBUS; TestPoint_Keystone_5005-5009_Compact; not fitted
TP2: +3V3; TestPoint_Keystone_5005-5009_Compact; not fitted
TP3: +VLED; TestPoint_Keystone_5005-5009_Compact; not fitted
TP4: LED-5V-EN; TestPoint_Keystone_5005-5009_Compact; not fitted
TP5: Ambient-Light-SNS; TestPoint_Keystone_5005-5009_Compact; not fitted
TP6: LVL-Shifter-EN; TestPoint_Keystone_5005-5009_Compact; not fitted
TP7: Ferries-S-MCU; TestPoint_Keystone_5005-5009_Compact; not fitted
TP8: Ferries-N-MCU; TestPoint_Keystone_5005-5009_Compact; not fitted
TP9: Rail-W-MCU; TestPoint_Keystone_5005-5009_Compact; not fitted
TP10: Rail-E-MCU; TestPoint_Keystone_5005-5009_Compact; not fitted
U1: ESP32-C3-MINI-1; LCSC C2838502
U2: SPX3819M5-L-3-3; SOT-23-5_L3.0-W1.6-P0.95-LS2.8-BR; LCSC Part C20617301
U3: USBLC6-2SC6; SOT-23-6_L2.9-W1.6-P0.95-LS2.8-BL; LCSC C7519
U4: SN74LVC8T245PWR; TSSOP-24_L7.8-W4.4-P0.65-LS6.4-BL; LCSC Part C27643
U5: TPU3013S5; SOT-23-5_L2.9-W1.6-P0.95-LS2.8-BR; LCSC Part C46472316
U6: BH1603FVC-TR; WSOF-6_L2.6-W1.6-P0.50-BL-EP; LCSC Part C132180

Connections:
+3V3: C1.2, C2.2, C5.1, C9.2, C12.1, C13.2, R1.1, R2.1, R5.2, R8.1, R10.1, R12.1, R13.1, R14.1, TP2.1, U1.3 (3V3), U2.5 (OUT), U4.1 (VCCA), U4.2 (DIR), U6.3 (VCC)
+VBUS: C3.2, C4.1, C8.1, F1.2, TP1.1, U2.1 (IN), U2.3 (EN), U5.5 (VIN)
+VLED: C6.1, C7.1, C14.2, C15.1, TP3.1, U4.23 (VCCB), U4.24 (VCCB), U5.1 (VOUT); also elsewhere on the board
/Ambient_Light_SNS: C10.2, R7.1, TP5.1, U1.6 (GPIO3/ADC1_CH3), U6.1 (IOUT)
/ESP32_BOOT: R13.2, SW2.2 (B), U1.23 (GPIO9)
/ESP32_EN: C11.1, R12.2, SW1.2 (B), U1.8 (EN/CHIP_PU)
/Ferries_N_Bus: R15.2, U4.21 (B1)
/Ferries_N_MCU: TP7.1, U1.19 (GPIO5/ADC2_CH0), U4.3 (A1)
/Ferries_S_Bus: R17.2, U4.20 (B2)
/Ferries_S_MCU: TP8.1, U1.18 (GPIO4/ADC1_CH4), U4.4 (A2)
/GC1_CFG: R8.2, R9.2, U6.5 (GC1)
/GC2_CFG: R10.2, R11.2, U6.6 (GC2)
/LVL_Shifter_EN_Active_Low: R14.2, TP6.1, U1.21 (GPIO7), U4.22 (~OE)
/Rail_E_Bus: R20.1, U4.18 (B4)
/Rail_E_MCU: TP10.1, U1.13 (GPIO1/ADC1_CH1/XTAL_32K_N), U4.6 (A4)
/Rail_W_Bus: R21.2, U4.19 (B3)
/Rail_W_MCU: TP9.1, U1.16 (GPIO10), U4.5 (A3)
/U0RXD: J2.3, U1.30 (GPIO20/U0RXD)
/U0TXD: J2.2, U1.31 (GPIO21/U0TXD)
/USBCC1: J1.A5 (CC1), R4.1
/USBCC2: J1.B5 (CC2), R3.1
/USBC_D+: J1.A6 (D+), J1.B6 (D+), U3.3 (I/O2)
/USBC_D-: J1.A7 (D-), J1.B7 (D-), U3.1 (I/O1)
/USB_D+: U1.27 (GPIO19/USB_D+), U3.4 (I/O2)
/USB_D-: U1.26 (GPIO18/USB_D-), U3.6 (I/O1)
/VLED_EN_Active_High: R6.1, TP4.1, U1.20 (GPIO6), U5.4 (EN/~EN)
/WiFi_LED: R23.2, U1.12 (GPIO0/ADC1_CH0/XTAL_32K_P)
Ferries N: R15.1, R16.1; also elsewhere on the board
Ferries S: R17.1, R18.1; also elsewhere on the board
GND: C1.1, C2.1, C3.1, C4.2, C5.2, C6.2, C7.2, C8.2, C9.1, C10.1, C11.2, C12.2, C13.1, C14.1, C15.2, D1.1, H1.1, H2.1, H3.1, H4.1, H5.1, H6.1, H7.1, H8.1, J1.A1 (GND), J1.A12 (GND), J1.B1 (GND), J1.B12 (GND), J1.S1 (SHIELD), J2.1, LED1.1 (K), LED2.1 (K), R3.2, R4.2, R6.2, R7.2, R9.1, R11.1, R16.2, R18.2, R19.2, R22.2, SW1.1 (A), SW2.1 (A), U1.1 (GND), U1.2 (GND), U1.11 (GND), U1.14 (GND), U1.36 (GND), U1.37 (GND), U1.38 (GND), U1.39 (GND), U1.40 (GND), U1.41 (GND), U1.42 (GND), U1.43 (GND), U1.44 (GND), U1.45 (GND), U1.46 (GND), U1.47 (GND), U1.48 (GND), U1.49 (GND), U1.50 (GND), U1.51 (GND), U1.52 (GND), U1.53 (GND), U2.2 (GND), U3.2 (GND), U4.7 (A5), U4.8 (A6), U4.9 (A7), U4.10 (A8), U4.11 (GND), U4.12 (GND), U4.13 (GND), U4.14 (B8), U4.15 (B7), U4.16 (B6), U4.17 (B5), U5.2 (GND), U6.2 (GND); also elsewhere on the board
unnamed: LED1.2 (A), R5.1
unnamed: LED2.2 (A), R23.1
unnamed: R1.2, U1.5 (GPIO2/ADC1_CH2)
unnamed: R2.2, U1.22 (GPIO8)
unnamed: D1.2, F1.1, J1.A4 (VBUS), J1.A9 (VBUS), J1.B4 (VBUS), J1.B9 (VBUS), U3.5 (VBUS)
Rail E: R19.1, R20.2; also elsewhere on the board
Rail W: R21.1, R22.1; also elsewhere on the board

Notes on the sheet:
Configured for H-Gain mode GC1=1, GC2=0
Ambient Light Sensor
A data to B Bus OE=0, DIR=1
Mounting Holes M3
LDO Regulator 5->3.3V
LED Power Switch
Logic Level Shifter
To ensure the high- impedance state during power up or power down, OE should be tied to VCC through a pullup resistor
ESP32-C3-MINI-1 MODULE
WiFi LED
ESP32 Boot
ESP32 Reset
USB-C Connector
UART Header

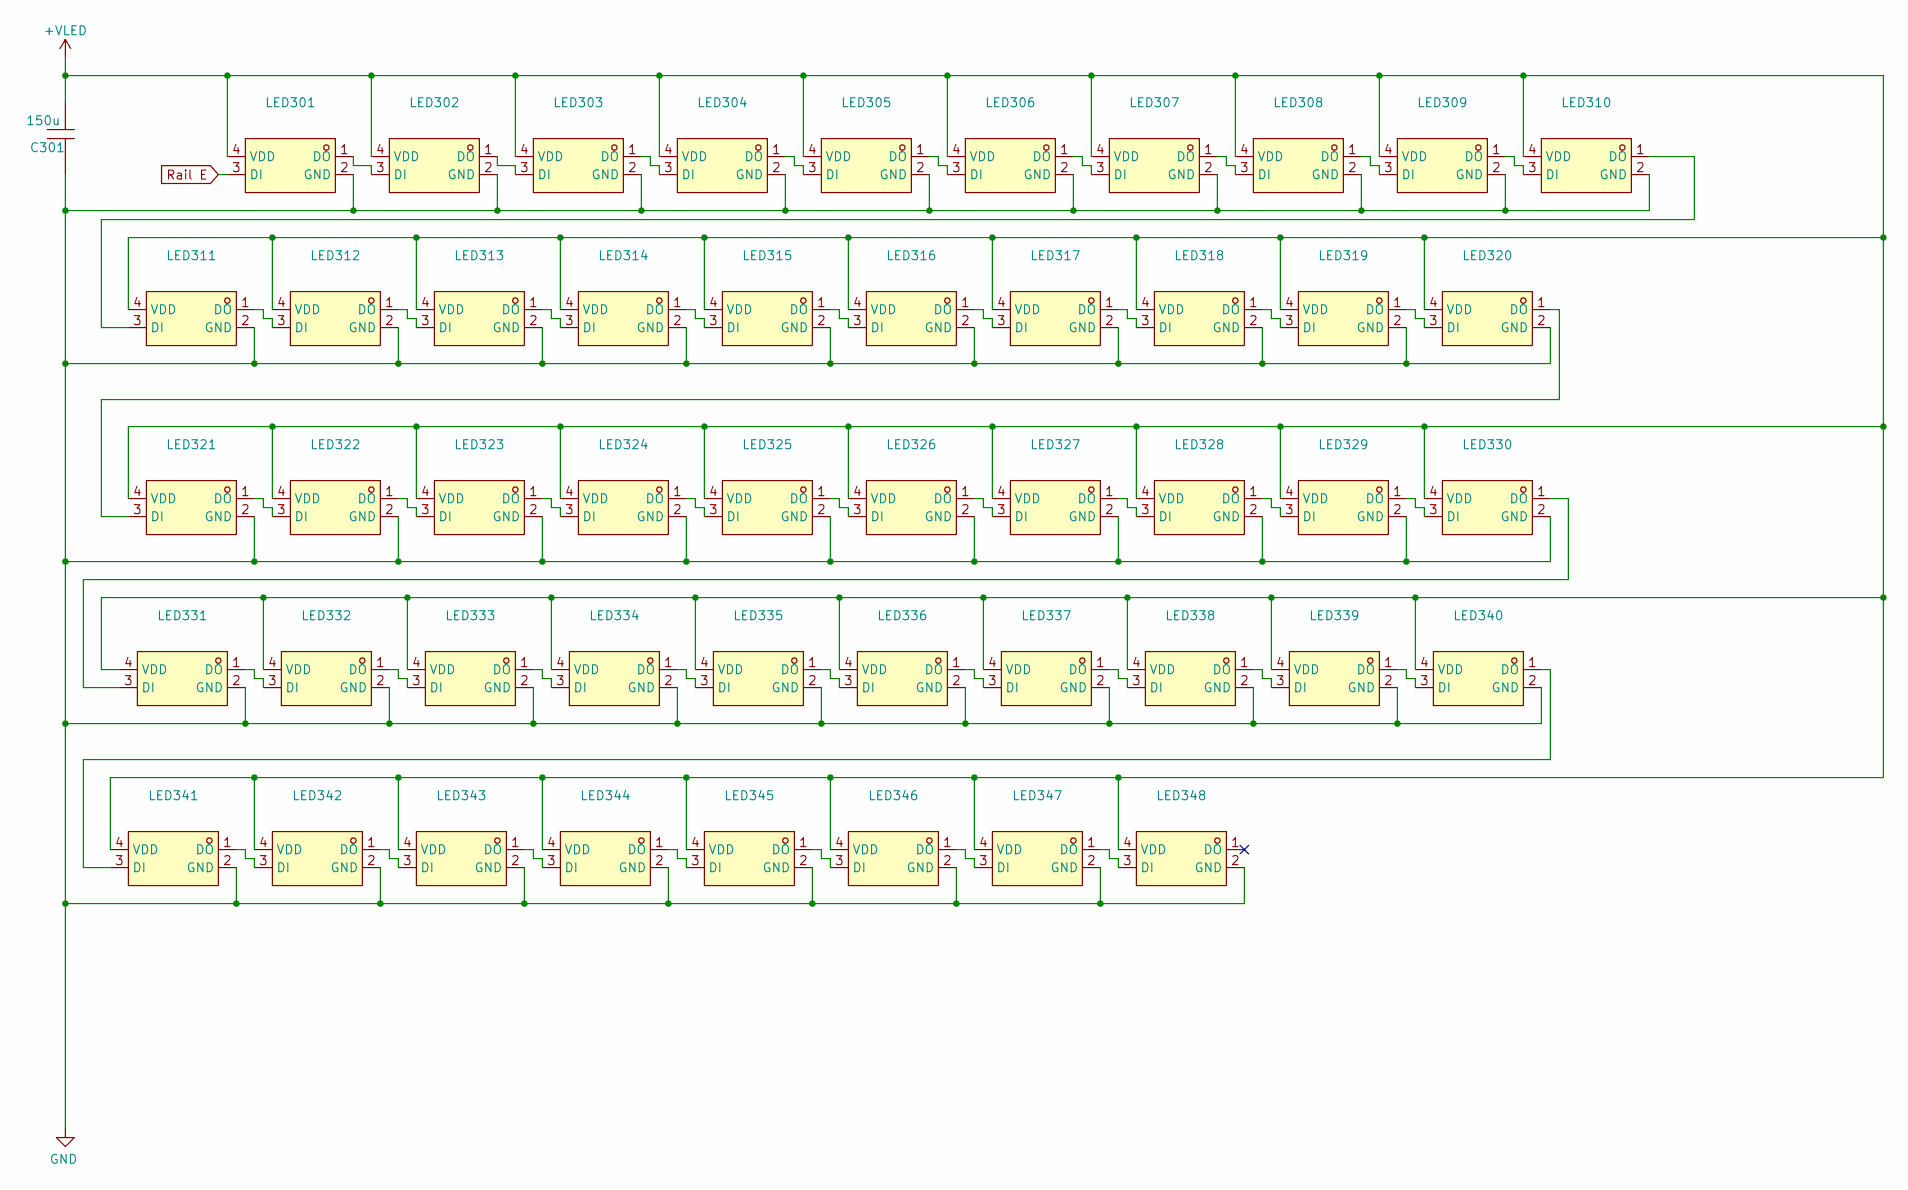
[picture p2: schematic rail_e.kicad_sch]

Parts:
C301: 150u; CAP-SMD_L3.5-W2.8; LCSC Part C212682
LED301, LED302, LED303, LED304, LED305, LED306, LED307, LED308, LED309, LED310, LED311, LED312, LED313, LED314, LED315, LED316, LED317, LED318, LED319, LED320, LED321, LED322, LED323, LED324, LED325, LED326, LED327, LED328, LED329, LED330, LED331, LED332, LED333, LED334, LED335, LED336, LED337, LED338, LED339, LED340, LED341, LED342, LED343, LED344, LED345, LED346, LED347, LED348: WS2812B-2020; LED-SMD_4P-L2.0-W2.0-TL_WS2812B-2020; LCSC Part C965555

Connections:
+VLED: C301.1, LED301.4 (VDD), LED302.4 (VDD), LED303.4 (VDD), LED304.4 (VDD), LED305.4 (VDD), LED306.4 (VDD), LED307.4 (VDD), LED308.4 (VDD), LED309.4 (VDD), LED310.4 (VDD), LED311.4 (VDD), LED312.4 (VDD), LED313.4 (VDD), LED314.4 (VDD), LED315.4 (VDD), LED316.4 (VDD), LED317.4 (VDD), LED318.4 (VDD), LED319.4 (VDD), LED320.4 (VDD), LED321.4 (VDD), LED322.4 (VDD), LED323.4 (VDD), LED324.4 (VDD), LED325.4 (VDD), LED326.4 (VDD), LED327.4 (VDD), LED328.4 (VDD), LED329.4 (VDD), LED330.4 (VDD), LED331.4 (VDD), LED332.4 (VDD), LED333.4 (VDD), LED334.4 (VDD), LED335.4 (VDD), LED336.4 (VDD), LED337.4 (VDD), LED338.4 (VDD), LED339.4 (VDD), LED340.4 (VDD), LED341.4 (VDD), LED342.4 (VDD), LED343.4 (VDD), LED344.4 (VDD), LED345.4 (VDD), LED346.4 (VDD), LED347.4 (VDD), LED348.4 (VDD); also elsewhere on the board
GND: C301.2, LED301.2 (GND), LED302.2 (GND), LED303.2 (GND), LED304.2 (GND), LED305.2 (GND), LED306.2 (GND), LED307.2 (GND), LED308.2 (GND), LED309.2 (GND), LED310.2 (GND), LED311.2 (GND), LED312.2 (GND), LED313.2 (GND), LED314.2 (GND), LED315.2 (GND), LED316.2 (GND), LED317.2 (GND), LED318.2 (GND), LED319.2 (GND), LED320.2 (GND), LED321.2 (GND), LED322.2 (GND), LED323.2 (GND), LED324.2 (GND), LED325.2 (GND), LED326.2 (GND), LED327.2 (GND), LED328.2 (GND), LED329.2 (GND), LED330.2 (GND), LED331.2 (GND), LED332.2 (GND), LED333.2 (GND), LED334.2 (GND), LED335.2 (GND), LED336.2 (GND), LED337.2 (GND), LED338.2 (GND), LED339.2 (GND), LED340.2 (GND), LED341.2 (GND), LED342.2 (GND), LED343.2 (GND), LED344.2 (GND), LED345.2 (GND), LED346.2 (GND), LED347.2 (GND), LED348.2 (GND); also elsewhere on the board
unnamed: LED301.1 (DO), LED302.3 (DI)
unnamed: LED302.1 (DO), LED303.3 (DI)
unnamed: LED303.1 (DO), LED304.3 (DI)
unnamed: LED304.1 (DO), LED305.3 (DI)
unnamed: LED305.1 (DO), LED306.3 (DI)
unnamed: LED306.1 (DO), LED307.3 (DI)
unnamed: LED307.1 (DO), LED308.3 (DI)
unnamed: LED308.1 (DO), LED309.3 (DI)
unnamed: LED309.1 (DO), LED310.3 (DI)
unnamed: LED310.1 (DO), LED311.3 (DI)
unnamed: LED311.1 (DO), LED312.3 (DI)
unnamed: LED312.1 (DO), LED313.3 (DI)
unnamed: LED313.1 (DO), LED314.3 (DI)
unnamed: LED314.1 (DO), LED315.3 (DI)
unnamed: LED315.1 (DO), LED316.3 (DI)
unnamed: LED316.1 (DO), LED317.3 (DI)
unnamed: LED317.1 (DO), LED318.3 (DI)
unnamed: LED318.1 (DO), LED319.3 (DI)
unnamed: LED319.1 (DO), LED320.3 (DI)
unnamed: LED320.1 (DO), LED321.3 (DI)
unnamed: LED321.1 (DO), LED322.3 (DI)
unnamed: LED322.1 (DO), LED323.3 (DI)
unnamed: LED323.1 (DO), LED324.3 (DI)
unnamed: LED324.1 (DO), LED325.3 (DI)
unnamed: LED325.1 (DO), LED326.3 (DI)
unnamed: LED326.1 (DO), LED327.3 (DI)
unnamed: LED327.1 (DO), LED328.3 (DI)
unnamed: LED328.1 (DO), LED329.3 (DI)
unnamed: LED329.1 (DO), LED330.3 (DI)
unnamed: LED330.1 (DO), LED331.3 (DI)
unnamed: LED331.1 (DO), LED332.3 (DI)
unnamed: LED332.1 (DO), LED333.3 (DI)
unnamed: LED333.1 (DO), LED334.3 (DI)
unnamed: LED334.1 (DO), LED335.3 (DI)
unnamed: LED335.1 (DO), LED336.3 (DI)
unnamed: LED336.1 (DO), LED337.3 (DI)
unnamed: LED337.1 (DO), LED338.3 (DI)
unnamed: LED338.1 (DO), LED339.3 (DI)
unnamed: LED339.1 (DO), LED340.3 (DI)
unnamed: LED340.1 (DO), LED341.3 (DI)
unnamed: LED341.1 (DO), LED342.3 (DI)
unnamed: LED342.1 (DO), LED343.3 (DI)
unnamed: LED343.1 (DO), LED344.3 (DI)
unnamed: LED344.1 (DO), LED345.3 (DI)
unnamed: LED345.1 (DO), LED346.3 (DI)
unnamed: LED346.1 (DO), LED347.3 (DI)
unnamed: LED347.1 (DO), LED348.3 (DI)
Rail E: LED301.3 (DI); also elsewhere on the board

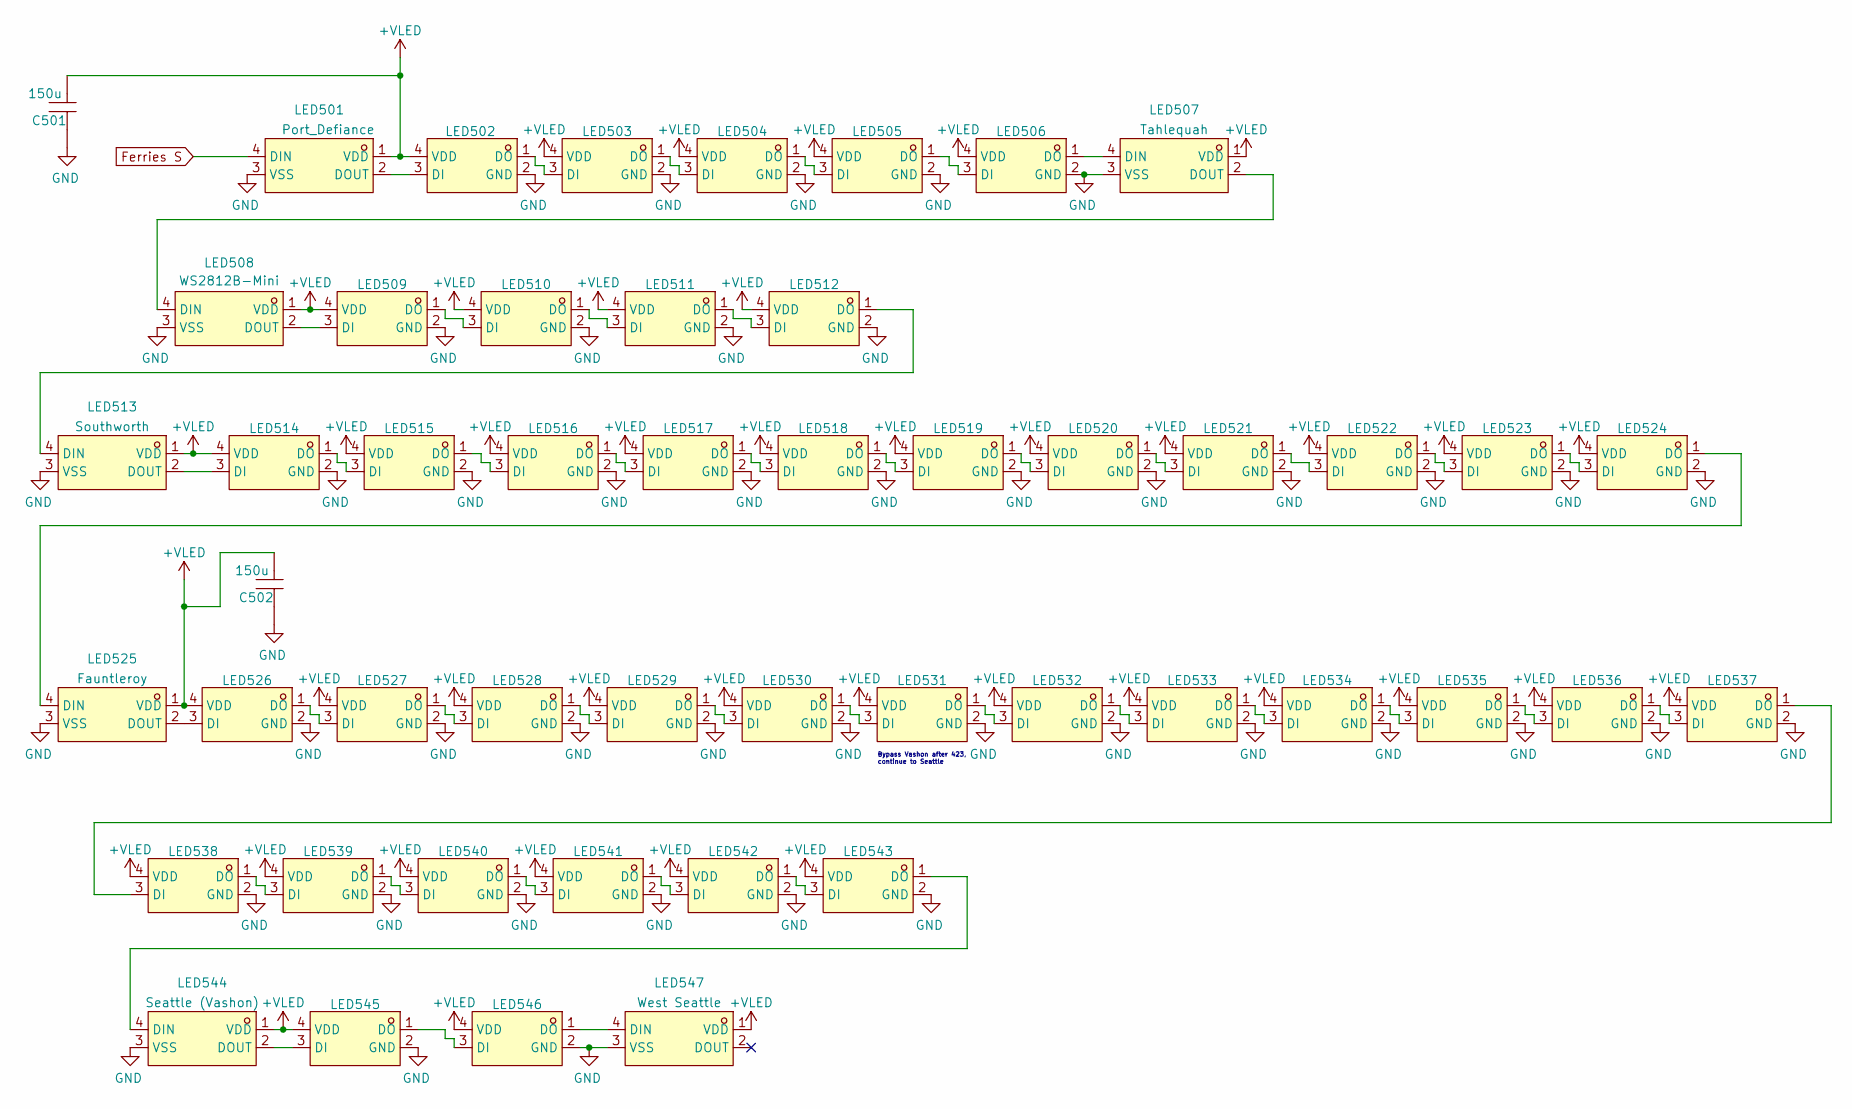
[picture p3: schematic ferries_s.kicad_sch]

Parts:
C501, C502: 150u; CAP-SMD_L3.5-W2.8; LCSC Part C212682
LED501, LED507, LED508, LED513, LED525, LED544, LED547: WS2812B-Mini; LED-SMD_4P-L3.5-W3.5-TL_WS2812B; LCSC Part C527089
LED502, LED503, LED504, LED505, LED506, LED509, LED510, LED511, LED512, LED514, LED515, LED516, LED517, LED518, LED519, LED520, LED521, LED522, LED523, LED524, LED526, LED527, LED528, LED529, LED530, LED531, LED532, LED533, LED534, LED535, LED536, LED537, LED538, LED539, LED540, LED541, LED542, LED543, LED545, LED546: WS2812B-2020; LED-SMD_4P-L2.0-W2.0-TL_WS2812B-2020; LCSC Part C965555

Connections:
+VLED: C501.1, C502.1, LED501.1 (VDD), LED502.4 (VDD), LED503.4 (VDD), LED504.4 (VDD), LED505.4 (VDD), LED506.4 (VDD), LED507.1 (VDD), LED508.1 (VDD), LED509.4 (VDD), LED510.4 (VDD), LED511.4 (VDD), LED512.4 (VDD), LED513.1 (VDD), LED514.4 (VDD), LED515.4 (VDD), LED516.4 (VDD), LED517.4 (VDD), LED518.4 (VDD), LED519.4 (VDD), LED520.4 (VDD), LED521.4 (VDD), LED522.4 (VDD), LED523.4 (VDD), LED524.4 (VDD), LED525.1 (VDD), LED526.4 (VDD), LED527.4 (VDD), LED528.4 (VDD), LED529.4 (VDD), LED530.4 (VDD), LED531.4 (VDD), LED532.4 (VDD), LED533.4 (VDD), LED534.4 (VDD), LED535.4 (VDD), LED536.4 (VDD), LED537.4 (VDD), LED538.4 (VDD), LED539.4 (VDD), LED540.4 (VDD), LED541.4 (VDD), LED542.4 (VDD), LED543.4 (VDD), LED544.1 (VDD), LED545.4 (VDD), LED546.4 (VDD), LED547.1 (VDD); also elsewhere on the board
Ferries S: LED501.4 (DIN); also elsewhere on the board
GND: C501.2, C502.2, LED501.3 (VSS), LED502.2 (GND), LED503.2 (GND), LED504.2 (GND), LED505.2 (GND), LED506.2 (GND), LED507.3 (VSS), LED508.3 (VSS), LED509.2 (GND), LED510.2 (GND), LED511.2 (GND), LED512.2 (GND), LED513.3 (VSS), LED514.2 (GND), LED515.2 (GND), LED516.2 (GND), LED517.2 (GND), LED518.2 (GND), LED519.2 (GND), LED520.2 (GND), LED521.2 (GND), LED522.2 (GND), LED523.2 (GND), LED524.2 (GND), LED525.3 (VSS), LED526.2 (GND), LED527.2 (GND), LED528.2 (GND), LED529.2 (GND), LED530.2 (GND), LED531.2 (GND), LED532.2 (GND), LED533.2 (GND), LED534.2 (GND), LED535.2 (GND), LED536.2 (GND), LED537.2 (GND), LED538.2 (GND), LED539.2 (GND), LED540.2 (GND), LED541.2 (GND), LED542.2 (GND), LED543.2 (GND), LED544.3 (VSS), LED545.2 (GND), LED546.2 (GND), LED547.3 (VSS); also elsewhere on the board
unnamed: LED501.2 (DOUT), LED502.3 (DI)
unnamed: LED502.1 (DO), LED503.3 (DI)
unnamed: LED503.1 (DO), LED504.3 (DI)
unnamed: LED504.1 (DO), LED505.3 (DI)
unnamed: LED505.1 (DO), LED506.3 (DI)
unnamed: LED506.1 (DO), LED507.4 (DIN)
unnamed: LED507.2 (DOUT), LED508.4 (DIN)
unnamed: LED508.2 (DOUT), LED509.3 (DI)
unnamed: LED509.1 (DO), LED510.3 (DI)
unnamed: LED510.1 (DO), LED511.3 (DI)
unnamed: LED511.1 (DO), LED512.3 (DI)
unnamed: LED512.1 (DO), LED513.4 (DIN)
unnamed: LED513.2 (DOUT), LED514.3 (DI)
unnamed: LED514.1 (DO), LED515.3 (DI)
unnamed: LED515.1 (DO), LED516.3 (DI)
unnamed: LED516.1 (DO), LED517.3 (DI)
unnamed: LED517.1 (DO), LED518.3 (DI)
unnamed: LED518.1 (DO), LED519.3 (DI)
unnamed: LED519.1 (DO), LED520.3 (DI)
unnamed: LED520.1 (DO), LED521.3 (DI)
unnamed: LED521.1 (DO), LED522.3 (DI)
unnamed: LED522.1 (DO), LED523.3 (DI)
unnamed: LED523.1 (DO), LED524.3 (DI)
unnamed: LED524.1 (DO), LED525.4 (DIN)
unnamed: LED525.2 (DOUT), LED526.3 (DI)
unnamed: LED526.1 (DO), LED527.3 (DI)
unnamed: LED527.1 (DO), LED528.3 (DI)
unnamed: LED528.1 (DO), LED529.3 (DI)
unnamed: LED529.1 (DO), LED530.3 (DI)
unnamed: LED530.1 (DO), LED531.3 (DI)
unnamed: LED531.1 (DO), LED532.3 (DI)
unnamed: LED532.1 (DO), LED533.3 (DI)
unnamed: LED533.1 (DO), LED534.3 (DI)
unnamed: LED534.1 (DO), LED535.3 (DI)
unnamed: LED535.1 (DO), LED536.3 (DI)
unnamed: LED536.1 (DO), LED537.3 (DI)
unnamed: LED537.1 (DO), LED538.3 (DI)
unnamed: LED538.1 (DO), LED539.3 (DI)
unnamed: LED539.1 (DO), LED540.3 (DI)
unnamed: LED540.1 (DO), LED541.3 (DI)
unnamed: LED541.1 (DO), LED542.3 (DI)
unnamed: LED542.1 (DO), LED543.3 (DI)
unnamed: LED543.1 (DO), LED544.4 (DIN)
unnamed: LED544.2 (DOUT), LED545.3 (DI)
unnamed: LED545.1 (DO), LED546.3 (DI)
unnamed: LED546.1 (DO), LED547.4 (DIN)

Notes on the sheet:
Bypass Vashon after 423, continue to Seattle

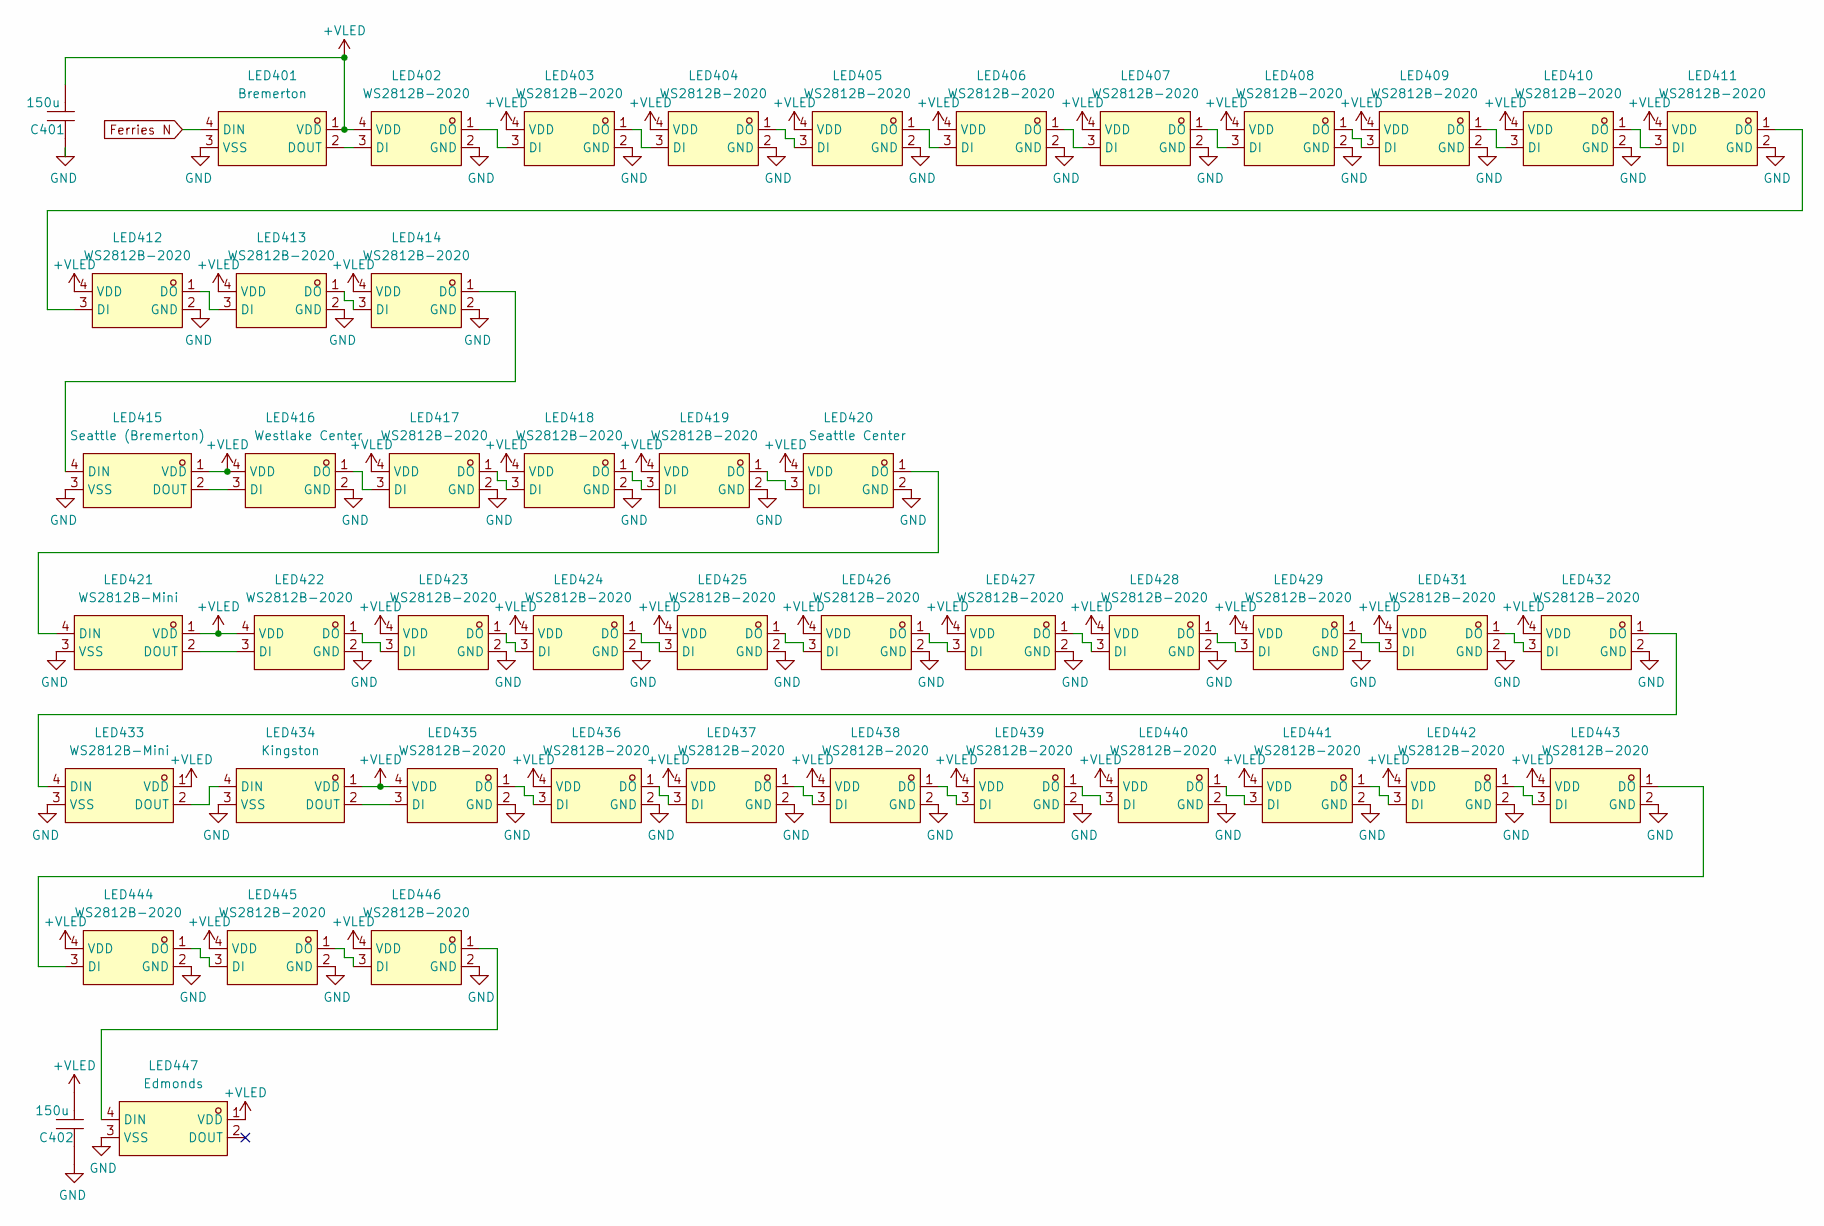
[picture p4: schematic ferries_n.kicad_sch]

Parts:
C401, C402: 150u; CAP-SMD_L3.5-W2.8; LCSC Part C212682
LED401, LED415, LED421, LED433, LED434, LED447: WS2812B-Mini; LED-SMD_4P-L3.5-W3.5-TL_WS2812B; LCSC Part C527089
LED402, LED403, LED404, LED405, LED406, LED407, LED408, LED409, LED410, LED411, LED412, LED413, LED414, LED416, LED417, LED418, LED419, LED420, LED422, LED423, LED424, LED425, LED426, LED427, LED428, LED429, LED431, LED432, LED435, LED436, LED437, LED438, LED439, LED440, LED441, LED442, LED443, LED444, LED445, LED446: WS2812B-2020; LED-SMD_4P-L2.0-W2.0-TL_WS2812B-2020; LCSC Part C965555

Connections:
+VLED: C401.1, C402.1, LED401.1 (VDD), LED402.4 (VDD), LED403.4 (VDD), LED404.4 (VDD), LED405.4 (VDD), LED406.4 (VDD), LED407.4 (VDD), LED408.4 (VDD), LED409.4 (VDD), LED410.4 (VDD), LED411.4 (VDD), LED412.4 (VDD), LED413.4 (VDD), LED414.4 (VDD), LED415.1 (VDD), LED416.4 (VDD), LED417.4 (VDD), LED418.4 (VDD), LED419.4 (VDD), LED420.4 (VDD), LED421.1 (VDD), LED422.4 (VDD), LED423.4 (VDD), LED424.4 (VDD), LED425.4 (VDD), LED426.4 (VDD), LED427.4 (VDD), LED428.4 (VDD), LED429.4 (VDD), LED431.4 (VDD), LED432.4 (VDD), LED433.1 (VDD), LED434.1 (VDD), LED435.4 (VDD), LED436.4 (VDD), LED437.4 (VDD), LED438.4 (VDD), LED439.4 (VDD), LED440.4 (VDD), LED441.4 (VDD), LED442.4 (VDD), LED443.4 (VDD), LED444.4 (VDD), LED445.4 (VDD), LED446.4 (VDD), LED447.1 (VDD); also elsewhere on the board
Ferries N: LED401.4 (DIN); also elsewhere on the board
GND: C401.2, C402.2, LED401.3 (VSS), LED402.2 (GND), LED403.2 (GND), LED404.2 (GND), LED405.2 (GND), LED406.2 (GND), LED407.2 (GND), LED408.2 (GND), LED409.2 (GND), LED410.2 (GND), LED411.2 (GND), LED412.2 (GND), LED413.2 (GND), LED414.2 (GND), LED415.3 (VSS), LED416.2 (GND), LED417.2 (GND), LED418.2 (GND), LED419.2 (GND), LED420.2 (GND), LED421.3 (VSS), LED422.2 (GND), LED423.2 (GND), LED424.2 (GND), LED425.2 (GND), LED426.2 (GND), LED427.2 (GND), LED428.2 (GND), LED429.2 (GND), LED431.2 (GND), LED432.2 (GND), LED433.3 (VSS), LED434.3 (VSS), LED435.2 (GND), LED436.2 (GND), LED437.2 (GND), LED438.2 (GND), LED439.2 (GND), LED440.2 (GND), LED441.2 (GND), LED442.2 (GND), LED443.2 (GND), LED444.2 (GND), LED445.2 (GND), LED446.2 (GND), LED447.3 (VSS); also elsewhere on the board
unnamed: LED401.2 (DOUT), LED402.3 (DI)
unnamed: LED402.1 (DO), LED403.3 (DI)
unnamed: LED403.1 (DO), LED404.3 (DI)
unnamed: LED404.1 (DO), LED405.3 (DI)
unnamed: LED405.1 (DO), LED406.3 (DI)
unnamed: LED406.1 (DO), LED407.3 (DI)
unnamed: LED407.1 (DO), LED408.3 (DI)
unnamed: LED408.1 (DO), LED409.3 (DI)
unnamed: LED409.1 (DO), LED410.3 (DI)
unnamed: LED410.1 (DO), LED411.3 (DI)
unnamed: LED411.1 (DO), LED412.3 (DI)
unnamed: LED412.1 (DO), LED413.3 (DI)
unnamed: LED413.1 (DO), LED414.3 (DI)
unnamed: LED414.1 (DO), LED415.4 (DIN)
unnamed: LED415.2 (DOUT), LED416.3 (DI)
unnamed: LED416.1 (DO), LED417.3 (DI)
unnamed: LED417.1 (DO), LED418.3 (DI)
unnamed: LED418.1 (DO), LED419.3 (DI)
unnamed: LED419.1 (DO), LED420.3 (DI)
unnamed: LED420.1 (DO), LED421.4 (DIN)
unnamed: LED421.2 (DOUT), LED422.3 (DI)
unnamed: LED422.1 (DO), LED423.3 (DI)
unnamed: LED423.1 (DO), LED424.3 (DI)
unnamed: LED424.1 (DO), LED425.3 (DI)
unnamed: LED425.1 (DO), LED426.3 (DI)
unnamed: LED426.1 (DO), LED427.3 (DI)
unnamed: LED427.1 (DO), LED428.3 (DI)
unnamed: LED428.1 (DO), LED429.3 (DI)
unnamed: LED429.1 (DO), LED431.3 (DI)
unnamed: LED431.1 (DO), LED432.3 (DI)
unnamed: LED432.1 (DO), LED433.4 (DIN)
unnamed: LED433.2 (DOUT), LED434.4 (DIN)
unnamed: LED434.2 (DOUT), LED435.3 (DI)
unnamed: LED435.1 (DO), LED436.3 (DI)
unnamed: LED436.1 (DO), LED437.3 (DI)
unnamed: LED437.1 (DO), LED438.3 (DI)
unnamed: LED438.1 (DO), LED439.3 (DI)
unnamed: LED439.1 (DO), LED440.3 (DI)
unnamed: LED440.1 (DO), LED441.3 (DI)
unnamed: LED441.1 (DO), LED442.3 (DI)
unnamed: LED442.1 (DO), LED443.3 (DI)
unnamed: LED443.1 (DO), LED444.3 (DI)
unnamed: LED444.1 (DO), LED445.3 (DI)
unnamed: LED445.1 (DO), LED446.3 (DI)
unnamed: LED446.1 (DO), LED447.4 (DIN)

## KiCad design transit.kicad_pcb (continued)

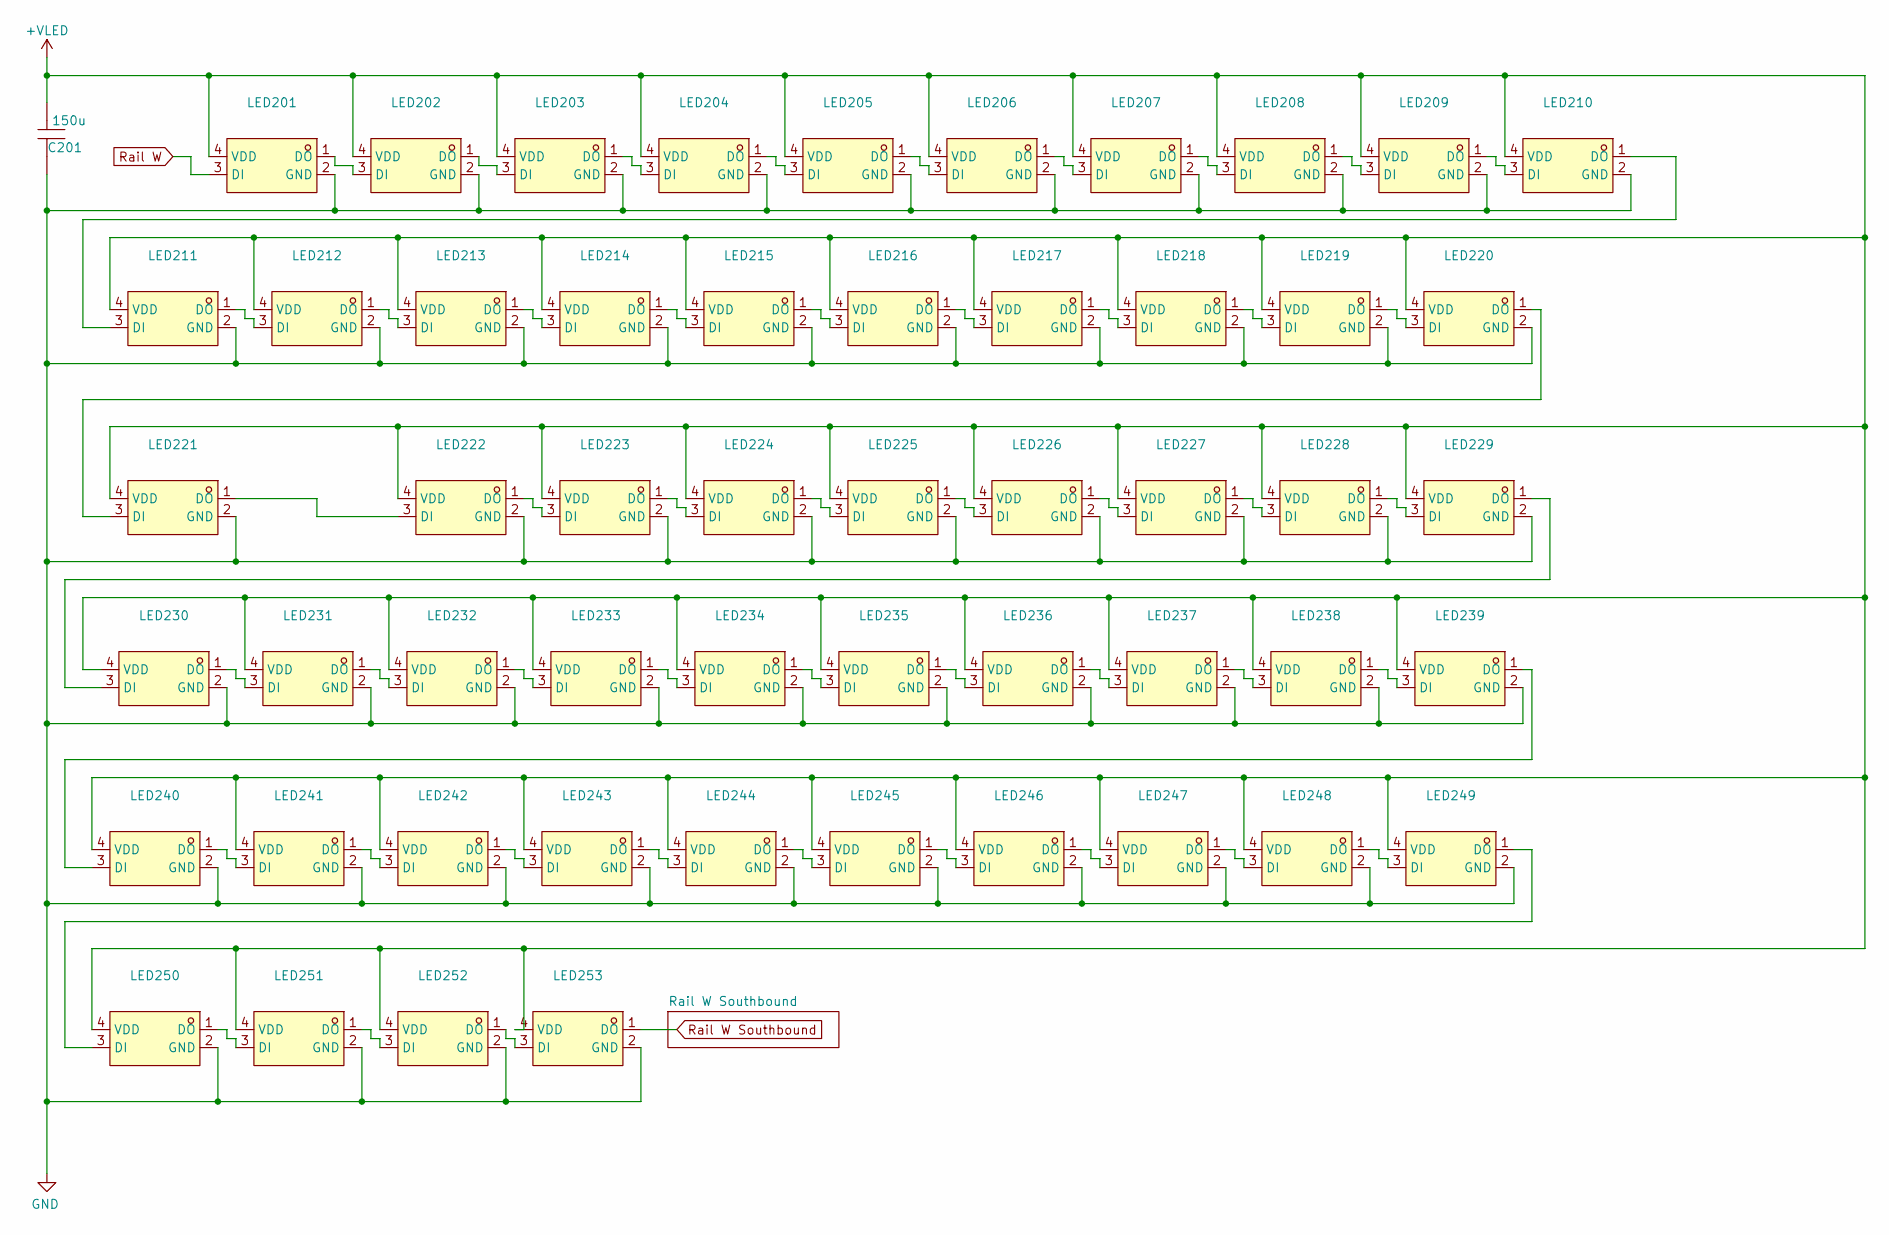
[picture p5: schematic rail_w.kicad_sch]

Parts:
C201: 150u; CAP-SMD_L3.5-W2.8; LCSC Part C212682
LED201, LED202, LED203, LED204, LED205, LED206, LED207, LED208, LED209, LED210, LED211, LED212, LED213, LED214, LED215, LED216, LED217, LED218, LED219, LED220, LED221, LED222, LED223, LED224, LED225, LED226, LED227, LED228, LED229, LED230, LED231, LED232, LED233, LED234, LED235, LED236, LED237, LED238, LED239, LED240, LED241, LED242, LED243, LED244, LED245, LED246, LED247, LED248, LED249, LED250, LED251, LED252, LED253: WS2812B-2020; LED-SMD_4P-L2.0-W2.0-TL_WS2812B-2020; LCSC Part C965555

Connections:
+VLED: C201.1, LED201.4 (VDD), LED202.4 (VDD), LED203.4 (VDD), LED204.4 (VDD), LED205.4 (VDD), LED206.4 (VDD), LED207.4 (VDD), LED208.4 (VDD), LED209.4 (VDD), LED210.4 (VDD), LED211.4 (VDD), LED212.4 (VDD), LED213.4 (VDD), LED214.4 (VDD), LED215.4 (VDD), LED216.4 (VDD), LED217.4 (VDD), LED218.4 (VDD), LED219.4 (VDD), LED220.4 (VDD), LED221.4 (VDD), LED222.4 (VDD), LED223.4 (VDD), LED224.4 (VDD), LED225.4 (VDD), LED226.4 (VDD), LED227.4 (VDD), LED228.4 (VDD), LED229.4 (VDD), LED230.4 (VDD), LED231.4 (VDD), LED232.4 (VDD), LED233.4 (VDD), LED234.4 (VDD), LED235.4 (VDD), LED236.4 (VDD), LED237.4 (VDD), LED238.4 (VDD), LED239.4 (VDD), LED240.4 (VDD), LED241.4 (VDD), LED242.4 (VDD), LED243.4 (VDD), LED244.4 (VDD), LED245.4 (VDD), LED246.4 (VDD), LED247.4 (VDD), LED248.4 (VDD), LED249.4 (VDD), LED250.4 (VDD), LED251.4 (VDD), LED252.4 (VDD), LED253.4 (VDD); also elsewhere on the board
GND: C201.2, LED201.2 (GND), LED202.2 (GND), LED203.2 (GND), LED204.2 (GND), LED205.2 (GND), LED206.2 (GND), LED207.2 (GND), LED208.2 (GND), LED209.2 (GND), LED210.2 (GND), LED211.2 (GND), LED212.2 (GND), LED213.2 (GND), LED214.2 (GND), LED215.2 (GND), LED216.2 (GND), LED217.2 (GND), LED218.2 (GND), LED219.2 (GND), LED220.2 (GND), LED221.2 (GND), LED222.2 (GND), LED223.2 (GND), LED224.2 (GND), LED225.2 (GND), LED226.2 (GND), LED227.2 (GND), LED228.2 (GND), LED229.2 (GND), LED230.2 (GND), LED231.2 (GND), LED232.2 (GND), LED233.2 (GND), LED234.2 (GND), LED235.2 (GND), LED236.2 (GND), LED237.2 (GND), LED238.2 (GND), LED239.2 (GND), LED240.2 (GND), LED241.2 (GND), LED242.2 (GND), LED243.2 (GND), LED244.2 (GND), LED245.2 (GND), LED246.2 (GND), LED247.2 (GND), LED248.2 (GND), LED249.2 (GND), LED250.2 (GND), LED251.2 (GND), LED252.2 (GND), LED253.2 (GND); also elsewhere on the board
unnamed: LED201.1 (DO), LED202.3 (DI)
unnamed: LED202.1 (DO), LED203.3 (DI)
unnamed: LED203.1 (DO), LED204.3 (DI)
unnamed: LED204.1 (DO), LED205.3 (DI)
unnamed: LED205.1 (DO), LED206.3 (DI)
unnamed: LED206.1 (DO), LED207.3 (DI)
unnamed: LED207.1 (DO), LED208.3 (DI)
unnamed: LED208.1 (DO), LED209.3 (DI)
unnamed: LED209.1 (DO), LED210.3 (DI)
unnamed: LED210.1 (DO), LED211.3 (DI)
unnamed: LED211.1 (DO), LED212.3 (DI)
unnamed: LED212.1 (DO), LED213.3 (DI)
unnamed: LED213.1 (DO), LED214.3 (DI)
unnamed: LED214.1 (DO), LED215.3 (DI)
unnamed: LED215.1 (DO), LED216.3 (DI)
unnamed: LED216.1 (DO), LED217.3 (DI)
unnamed: LED217.1 (DO), LED218.3 (DI)
unnamed: LED218.1 (DO), LED219.3 (DI)
unnamed: LED219.1 (DO), LED220.3 (DI)
unnamed: LED220.1 (DO), LED221.3 (DI)
unnamed: LED221.1 (DO), LED222.3 (DI)
unnamed: LED222.1 (DO), LED223.3 (DI)
unnamed: LED223.1 (DO), LED224.3 (DI)
unnamed: LED224.1 (DO), LED225.3 (DI)
unnamed: LED225.1 (DO), LED226.3 (DI)
unnamed: LED226.1 (DO), LED227.3 (DI)
unnamed: LED227.1 (DO), LED228.3 (DI)
unnamed: LED228.1 (DO), LED229.3 (DI)
unnamed: LED229.1 (DO), LED230.3 (DI)
unnamed: LED230.1 (DO), LED231.3 (DI)
unnamed: LED231.1 (DO), LED232.3 (DI)
unnamed: LED232.1 (DO), LED233.3 (DI)
unnamed: LED233.1 (DO), LED234.3 (DI)
unnamed: LED234.1 (DO), LED235.3 (DI)
unnamed: LED235.1 (DO), LED236.3 (DI)
unnamed: LED236.1 (DO), LED237.3 (DI)
unnamed: LED237.1 (DO), LED238.3 (DI)
unnamed: LED238.1 (DO), LED239.3 (DI)
unnamed: LED239.1 (DO), LED240.3 (DI)
unnamed: LED240.1 (DO), LED241.3 (DI)
unnamed: LED241.1 (DO), LED242.3 (DI)
unnamed: LED242.1 (DO), LED243.3 (DI)
unnamed: LED243.1 (DO), LED244.3 (DI)
unnamed: LED244.1 (DO), LED245.3 (DI)
unnamed: LED245.1 (DO), LED246.3 (DI)
unnamed: LED246.1 (DO), LED247.3 (DI)
unnamed: LED247.1 (DO), LED248.3 (DI)
unnamed: LED248.1 (DO), LED249.3 (DI)
unnamed: LED249.1 (DO), LED250.3 (DI)
unnamed: LED250.1 (DO), LED251.3 (DI)
unnamed: LED251.1 (DO), LED252.3 (DI)
unnamed: LED252.1 (DO), LED253.3 (DI)
Rail W: LED201.3 (DI); also elsewhere on the board
Rail W Southbound: LED253.1 (DO); also elsewhere on the board

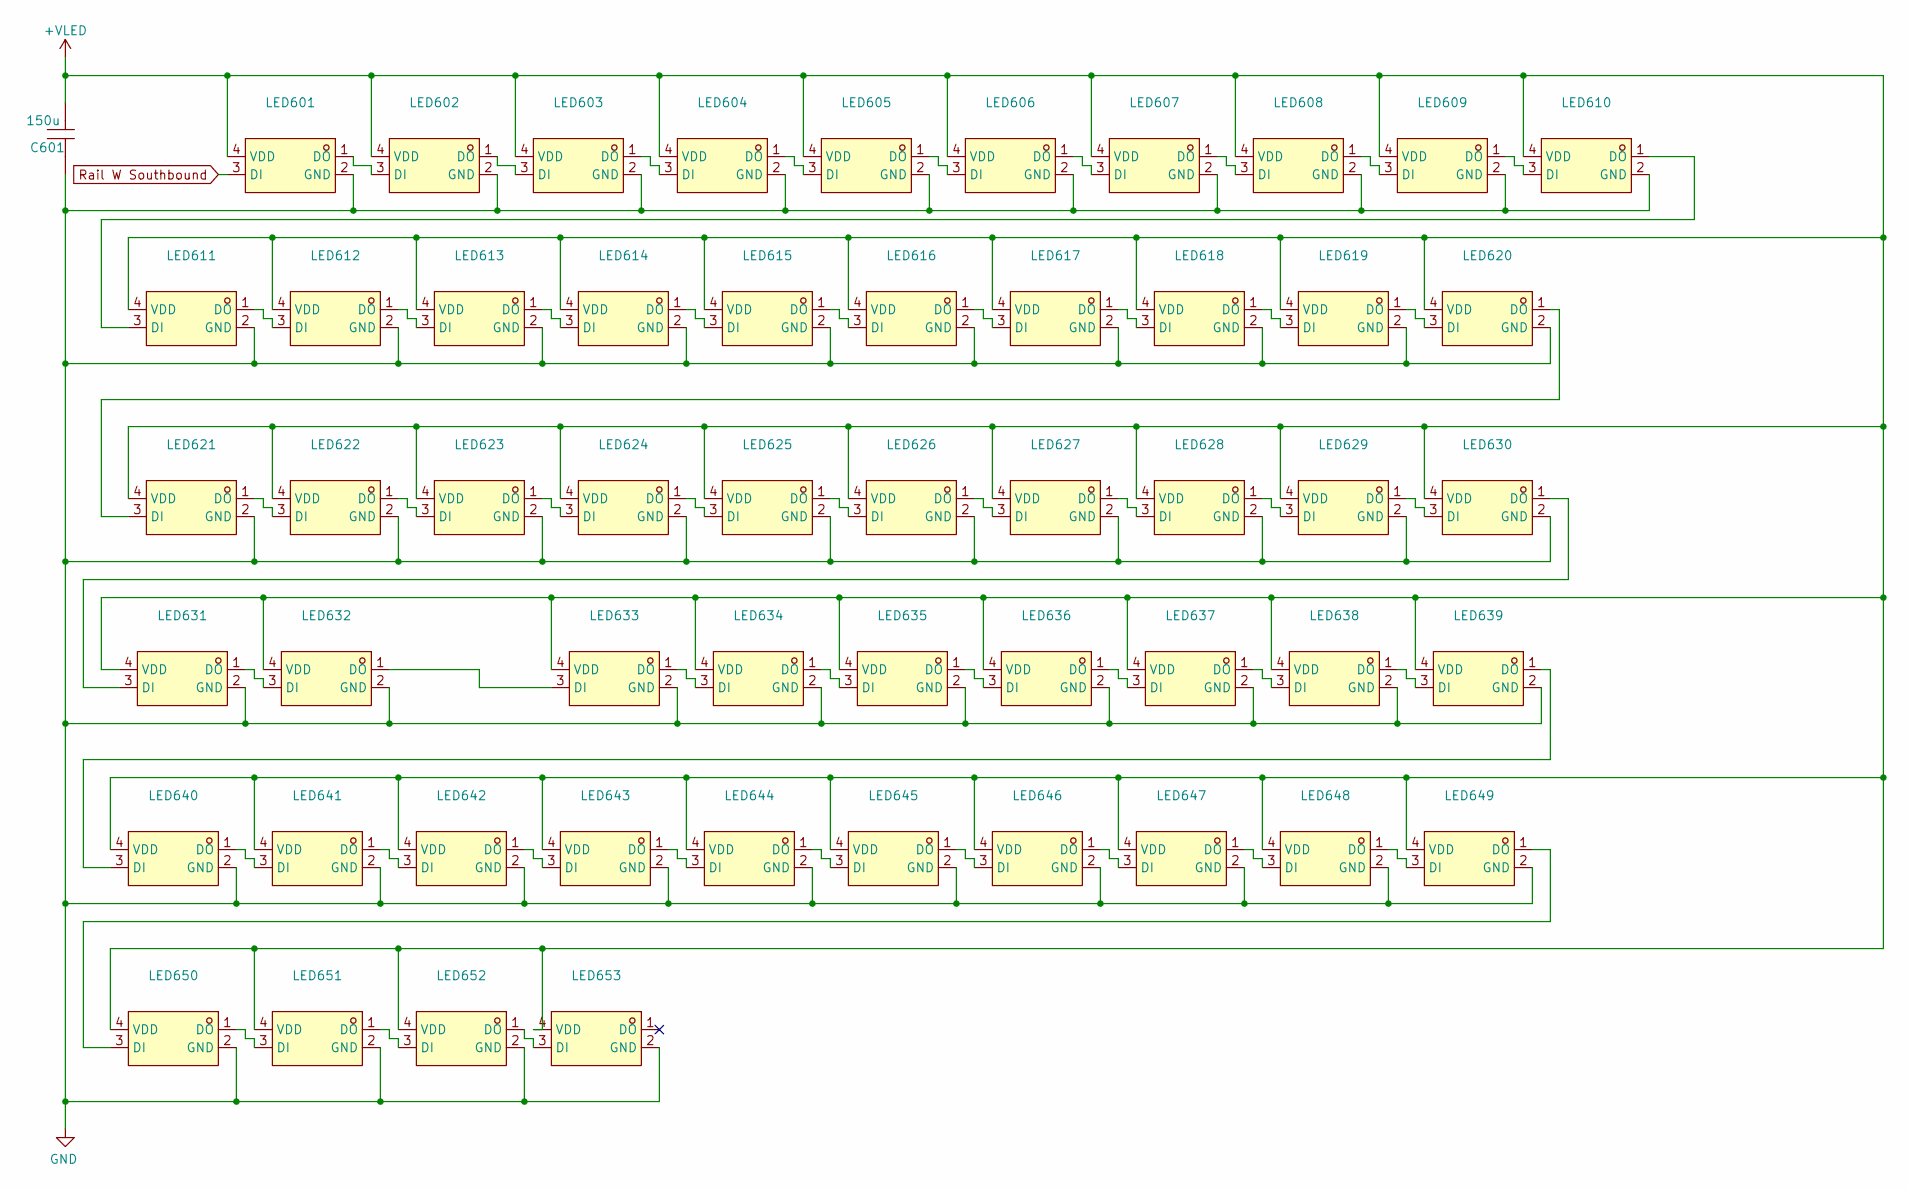
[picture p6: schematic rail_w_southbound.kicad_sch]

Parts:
C601: 150u; CAP-SMD_L3.5-W2.8; LCSC Part C212682
LED601, LED602, LED603, LED604, LED605, LED606, LED607, LED608, LED609, LED610, LED611, LED612, LED613, LED614, LED615, LED616, LED617, LED618, LED619, LED620, LED621, LED622, LED623, LED624, LED625, LED626, LED627, LED628, LED629, LED630, LED631, LED632, LED633, LED634, LED635, LED636, LED637, LED638, LED639, LED640, LED641, LED642, LED643, LED644, LED645, LED646, LED647, LED648, LED649, LED650, LED651, LED652, LED653: WS2812B-2020; LED-SMD_4P-L2.0-W2.0-TL_WS2812B-2020; LCSC Part C965555

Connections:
+VLED: C601.1, LED601.4 (VDD), LED602.4 (VDD), LED603.4 (VDD), LED604.4 (VDD), LED605.4 (VDD), LED606.4 (VDD), LED607.4 (VDD), LED608.4 (VDD), LED609.4 (VDD), LED610.4 (VDD), LED611.4 (VDD), LED612.4 (VDD), LED613.4 (VDD), LED614.4 (VDD), LED615.4 (VDD), LED616.4 (VDD), LED617.4 (VDD), LED618.4 (VDD), LED619.4 (VDD), LED620.4 (VDD), LED621.4 (VDD), LED622.4 (VDD), LED623.4 (VDD), LED624.4 (VDD), LED625.4 (VDD), LED626.4 (VDD), LED627.4 (VDD), LED628.4 (VDD), LED629.4 (VDD), LED630.4 (VDD), LED631.4 (VDD), LED632.4 (VDD), LED633.4 (VDD), LED634.4 (VDD), LED635.4 (VDD), LED636.4 (VDD), LED637.4 (VDD), LED638.4 (VDD), LED639.4 (VDD), LED640.4 (VDD), LED641.4 (VDD), LED642.4 (VDD), LED643.4 (VDD), LED644.4 (VDD), LED645.4 (VDD), LED646.4 (VDD), LED647.4 (VDD), LED648.4 (VDD), LED649.4 (VDD), LED650.4 (VDD), LED651.4 (VDD), LED652.4 (VDD), LED653.4 (VDD); also elsewhere on the board
GND: C601.2, LED601.2 (GND), LED602.2 (GND), LED603.2 (GND), LED604.2 (GND), LED605.2 (GND), LED606.2 (GND), LED607.2 (GND), LED608.2 (GND), LED609.2 (GND), LED610.2 (GND), LED611.2 (GND), LED612.2 (GND), LED613.2 (GND), LED614.2 (GND), LED615.2 (GND), LED616.2 (GND), LED617.2 (GND), LED618.2 (GND), LED619.2 (GND), LED620.2 (GND), LED621.2 (GND), LED622.2 (GND), LED623.2 (GND), LED624.2 (GND), LED625.2 (GND), LED626.2 (GND), LED627.2 (GND), LED628.2 (GND), LED629.2 (GND), LED630.2 (GND), LED631.2 (GND), LED632.2 (GND), LED633.2 (GND), LED634.2 (GND), LED635.2 (GND), LED636.2 (GND), LED637.2 (GND), LED638.2 (GND), LED639.2 (GND), LED640.2 (GND), LED641.2 (GND), LED642.2 (GND), LED643.2 (GND), LED644.2 (GND), LED645.2 (GND), LED646.2 (GND), LED647.2 (GND), LED648.2 (GND), LED649.2 (GND), LED650.2 (GND), LED651.2 (GND), LED652.2 (GND), LED653.2 (GND); also elsewhere on the board
unnamed: LED601.1 (DO), LED602.3 (DI)
unnamed: LED602.1 (DO), LED603.3 (DI)
unnamed: LED603.1 (DO), LED604.3 (DI)
unnamed: LED604.1 (DO), LED605.3 (DI)
unnamed: LED605.1 (DO), LED606.3 (DI)
unnamed: LED606.1 (DO), LED607.3 (DI)
unnamed: LED607.1 (DO), LED608.3 (DI)
unnamed: LED608.1 (DO), LED609.3 (DI)
unnamed: LED609.1 (DO), LED610.3 (DI)
unnamed: LED610.1 (DO), LED611.3 (DI)
unnamed: LED611.1 (DO), LED612.3 (DI)
unnamed: LED612.1 (DO), LED613.3 (DI)
unnamed: LED613.1 (DO), LED614.3 (DI)
unnamed: LED614.1 (DO), LED615.3 (DI)
unnamed: LED615.1 (DO), LED616.3 (DI)
unnamed: LED616.1 (DO), LED617.3 (DI)
unnamed: LED617.1 (DO), LED618.3 (DI)
unnamed: LED618.1 (DO), LED619.3 (DI)
unnamed: LED619.1 (DO), LED620.3 (DI)
unnamed: LED620.1 (DO), LED621.3 (DI)
unnamed: LED621.1 (DO), LED622.3 (DI)
unnamed: LED622.1 (DO), LED623.3 (DI)
unnamed: LED623.1 (DO), LED624.3 (DI)
unnamed: LED624.1 (DO), LED625.3 (DI)
unnamed: LED625.1 (DO), LED626.3 (DI)
unnamed: LED626.1 (DO), LED627.3 (DI)
unnamed: LED627.1 (DO), LED628.3 (DI)
unnamed: LED628.1 (DO), LED629.3 (DI)
unnamed: LED629.1 (DO), LED630.3 (DI)
unnamed: LED630.1 (DO), LED631.3 (DI)
unnamed: LED631.1 (DO), LED632.3 (DI)
unnamed: LED632.1 (DO), LED633.3 (DI)
unnamed: LED633.1 (DO), LED634.3 (DI)
unnamed: LED634.1 (DO), LED635.3 (DI)
unnamed: LED635.1 (DO), LED636.3 (DI)
unnamed: LED636.1 (DO), LED637.3 (DI)
unnamed: LED637.1 (DO), LED638.3 (DI)
unnamed: LED638.1 (DO), LED639.3 (DI)
unnamed: LED639.1 (DO), LED640.3 (DI)
unnamed: LED640.1 (DO), LED641.3 (DI)
unnamed: LED641.1 (DO), LED642.3 (DI)
unnamed: LED642.1 (DO), LED643.3 (DI)
unnamed: LED643.1 (DO), LED644.3 (DI)
unnamed: LED644.1 (DO), LED645.3 (DI)
unnamed: LED645.1 (DO), LED646.3 (DI)
unnamed: LED646.1 (DO), LED647.3 (DI)
unnamed: LED647.1 (DO), LED648.3 (DI)
unnamed: LED648.1 (DO), LED649.3 (DI)
unnamed: LED649.1 (DO), LED650.3 (DI)
unnamed: LED650.1 (DO), LED651.3 (DI)
unnamed: LED651.1 (DO), LED652.3 (DI)
unnamed: LED652.1 (DO), LED653.3 (DI)
Rail W Southbound: LED601.3 (DI); also elsewhere on the board

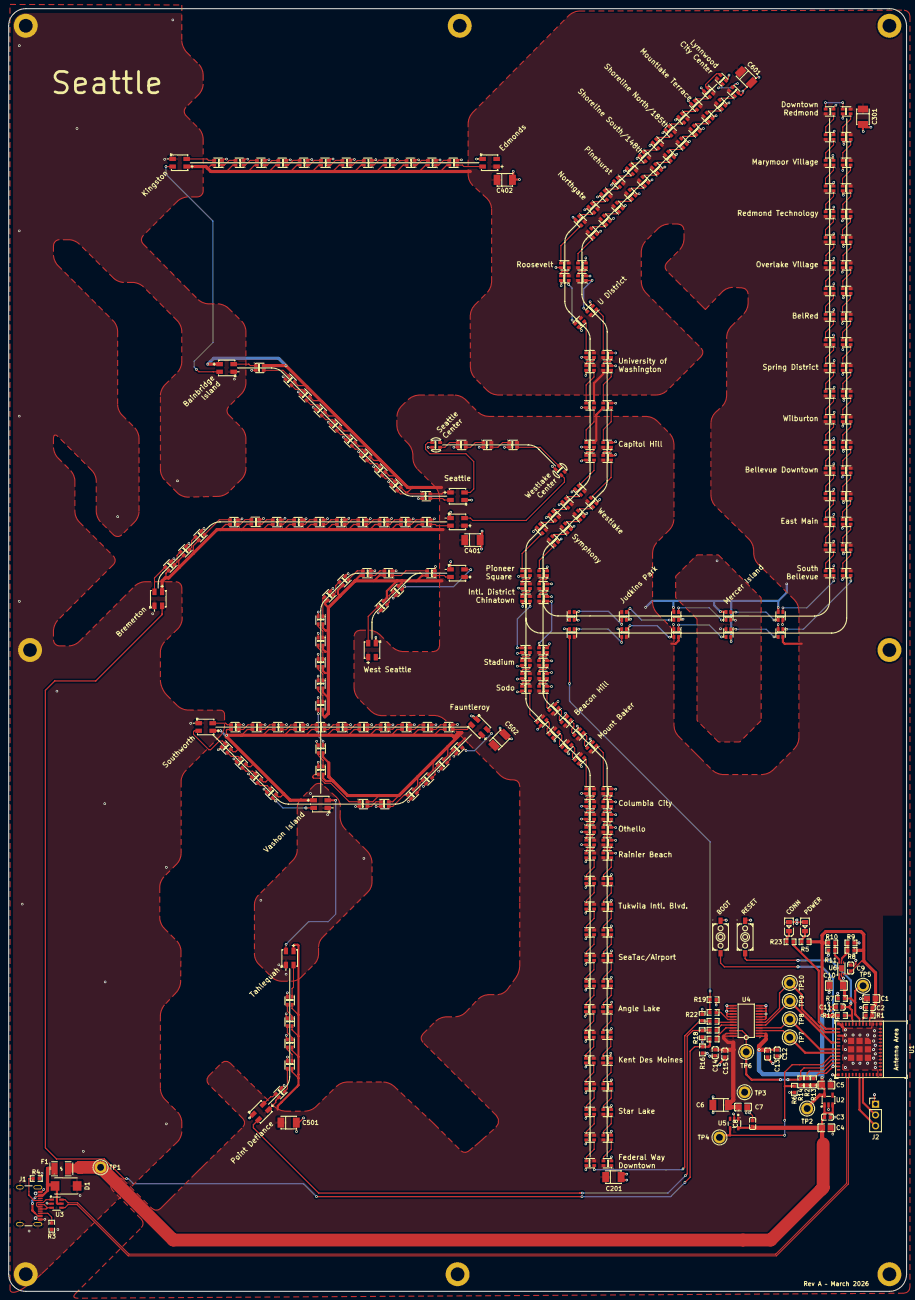
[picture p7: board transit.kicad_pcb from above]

Board: 2 copper layers, 210.0 x 300.0 mm, 324 parts (0 on the bottom side), 280 nets.

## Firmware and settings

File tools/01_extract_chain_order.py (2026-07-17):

#!/usr/bin/env python3
"""
Step 1: Extract LED daisy-chain wiring order from KiCad schematics.

Parses KiCad v9 .kicad_sch files (S-expression format) to determine the
wiring order of WS2812B LEDs on each chain. Traces DO→DI net connections
through wires to reconstruct the physical chain order.

Input:  Directory containing .kicad_sch files (main + sub-sheets)
Output: chain_order.json

Usage:
    python 01_extract_chain_order.py /path/to/kicad/project
    python 01_extract_chain_order.py /path/to/kicad/project --output chain_order.json
"""

import argparse
import json
import os
import re
import sys
from dataclasses import dataclass, field
from pathlib import Path
from typing import Optional


# ---------------------------------------------------------------------------
# S-expression parser (minimal, sufficient for KiCad schematic files)
# ---------------------------------------------------------------------------

def parse_sexpr(text: str) -> list:
    """Parse an S-expression string into nested Python lists and strings."""
    tokens = _tokenize(text)
    result, _ = _parse_tokens(tokens, 0)
    return result


def _tokenize(text: str) -> list[str]:
    """Tokenize S-expression text into a flat list of tokens."""
    tokens = []
    i = 0
    n = len(text)
    while i < n:
        c = text[i]
        if c in ' \t\n\r':
            i += 1
        elif c == '(':
            tokens.append('(')
            i += 1
        elif c == ')':
            tokens.append(')')
            i += 1
        elif c == '"':
            # Quoted string
            j = i + 1
            while j < n:
                if text[j] == '\\':
                    j += 2
                elif text[j] == '"':
                    break
                else:
                    j += 1
            tokens.append(text[i+1:j])  # strip quotes
            i = j + 1
        else:
            # Unquoted atom
            j = i
            while j < n and text[j] not in ' \t\n\r()':
                j += 1
            tokens.append(text[i:j])
            i = j
    return tokens


def _parse_tokens(tokens: list[str], pos: int) -> tuple[list, int]:
    """Recursively parse tokens starting at pos. Returns (parsed, new_pos)."""
    if tokens[pos] != '(':
        return tokens[pos], pos + 1

    pos += 1  # skip '('
    items = []
    while pos < len(tokens) and tokens[pos] != ')':
        item, pos = _parse_tokens(tokens, pos)
        items.append(item)
    pos += 1  # skip ')'
    return items, pos


# ---------------------------------------------------------------------------
# S-expression query helpers
# ---------------------------------------------------------------------------

def sexpr_tag(node) -> Optional[str]:
    """Get the tag (first element) of an S-expression list."""
    if isinstance(node, list) and len(node) > 0 and isinstance(node[0], str):
        return node[0]
    return None


def sexpr_find(node: list, tag: str) -> list:
    """Find all direct children with the given tag."""
    return [child for child in node if sexpr_tag(child) == tag]


def sexpr_find_one(node: list, tag: str):
    """Find first direct child with the given tag, or None."""
    for child in node:
        if sexpr_tag(child) == tag:
            return child
    return None


def sexpr_val(node: list, tag: str, default=None):
    """Get the value (second element) of a tagged child."""
    child = sexpr_find_one(node, tag)
    if child and len(child) > 1:
        return child[1]
    return default


# ---------------------------------------------------------------------------
# Data structures
# ---------------------------------------------------------------------------

@dataclass
class PinDef:
    """Pin definition from a library symbol."""
    number: str
    name: str
    x: float  # relative to symbol origin
    y: float


@dataclass
class LedSymbol:
    """An LED symbol instance in the schematic."""
    ref: str              # e.g. "LED411"
    lib_id: str           # e.g. "EasyEDA:WS2812B-2020"
    package: str          # "2020" or "mini"
    uuid: str
    x: float              # symbol placement position
    y: float
    mirror_y: bool
    rotation: float       # degrees
    # Absolute pin positions (computed)
    di_pin: tuple[float, float] = (0.0, 0.0)
    do_pin: tuple[float, float] = (0.0, 0.0)


@dataclass
class Wire:
    """A wire segment in the schematic."""
    x1: float
    y1: float
    x2: float
    y2: float


# ---------------------------------------------------------------------------
# Pin position definitions from library symbols
# ---------------------------------------------------------------------------

# WS2812B-2020 pin positions (relative to symbol origin, before transform):
#   Pin 1 (DO):  at (0, -2.54)
#   Pin 2 (GND): at (0, -5.08)
#   Pin 3 (DI):  at (17.78, -5.08)
#   Pin 4 (VDD): at (17.78, -2.54)
WS2812B_2020_DO = PinDef("1", "DO", 0.0, -2.54)
WS2812B_2020_DI = PinDef("3", "DI", 17.78, -5.08)

# WS2812B-MINI pin positions:
#   Pin 1 (VDD):  at (0, -2.54)
#   Pin 2 (DOUT): at (0, -5.08)
#   Pin 3 (VSS):  at (20.32, -5.08)
#   Pin 4 (DIN):  at (20.32, -2.54)
WS2812B_MINI_DO = PinDef("2", "DOUT", 0.0, -5.08)
WS2812B_MINI_DI = PinDef("4", "DIN", 20.32, -2.54)

# WS2812B-MINI-X2 uses the same schematic pin locations but the manufacturer's
# native pin numbering: 1 DIN, 2 VDD, 3 DOUT, 4 GND.
WS2812B_MINI_X2_DO = PinDef("3", "DOUT", 0.0, -5.08)
WS2812B_MINI_X2_DI = PinDef("1", "DIN", 20.32, -2.54)

# Map lib_id patterns to pin definitions
PIN_DEFS = {
    "WS2812B-2020": (WS2812B_2020_DI, WS2812B_2020_DO),
    "WS2812B-MINI": (WS2812B_MINI_DI, WS2812B_MINI_DO),
    "WS2812B-MINI-X2": (WS2812B_MINI_X2_DI, WS2812B_MINI_X2_DO),
}


def transform_pin(sym_x: float, sym_y: float, pin_x: float, pin_y: float,
                   mirror_y: bool, rotation: float) -> tuple[float, float]:
    """
    Transform a pin's relative position to absolute schematic coordinates.

    KiCad applies transforms in this order:
    1. Mirror Y (negate X)
    2. Rotate
    3. Translate to symbol position
    """
    px, py = pin_x, pin_y

    if mirror_y:
        px = -px

    # Apply rotation (KiCad uses degrees, CCW positive)
    if rotation != 0:
        import math
        rad = math.radians(rotation)
        cos_r = math.cos(rad)
        sin_r = math.sin(rad)
        px, py = px * cos_r - py * sin_r, px * sin_r + py * cos_r

    # Translate to symbol position
    abs_x = round(sym_x + px, 4)
    abs_y = round(sym_y + py, 4)
    return abs_x, abs_y


# ---------------------------------------------------------------------------
# Schematic parsing
# ---------------------------------------------------------------------------

def parse_schematic(filepath: Path) -> tuple[list[LedSymbol], list[Wire], Optional[str]]:
    """
    Parse a single .kicad_sch file. Returns (leds, wires, global_label).

    global_label is the chain input label (e.g. "Ferries N") if found.
    """
    text = filepath.read_text(encoding='utf-8')
    root = parse_sexpr(text)

    leds = []
    wires = []
    global_label = None

    for node in root:
        tag = sexpr_tag(node)

        if tag == 'symbol':
            led = _parse_led_symbol(node)
            if led:
                leds.append(led)

        elif tag == 'wire':
            wire = _parse_wire(node)
            if wire:
                wires.append(wire)

        elif tag == 'global_label':
            # The chain input label — the data signal entering this sub-sheet
            if len(node) > 1 and isinstance(node[1], str):
                label_text = node[1]
                # Only care about chain-related labels
                if any(name in label_text for name in ['Rail', 'Ferries']):
                    global_label = label_text

    return leds, wires, global_label


def _parse_led_symbol(node: list) -> Optional[LedSymbol]:
    """Parse a symbol node, returning LedSymbol if it's a WS2812B LED."""
    lib_id = sexpr_val(node, 'lib_id')
    if not lib_id or not isinstance(lib_id, str):
        return None

    # Identify LED type
    package = None
    if 'WS2812B-2020' in lib_id:
        package = '2020'
        pin_key = 'WS2812B-2020'
    elif 'WS2812B-MINI-X2' in lib_id:
        # Keep the downstream physical package schema at "mini" while selecting
        # the X2-specific electrical pin mapping separately.
        package = 'mini'
        pin_key = 'WS2812B-MINI-X2'
    elif 'WS2812B-MINI' in lib_id or 'WS2812B-Mini' in lib_id:
        package = 'mini'
        pin_key = 'WS2812B-MINI'
    else:
        return None

    # Get reference designator from instances
    ref = None
    instances = sexpr_find_one(node, 'instances')
    if instances:
        for project in sexpr_find(instances, 'project'):
            for path in sexpr_find(project, 'path'):
                r = sexpr_val(path, 'reference')
                if r and isinstance(r, str) and r.startswith('LED'):
                    ref = r
                    break

    # Fallback: get from Reference property
    if not ref:
        for prop in sexpr_find(node, 'property'):
            if len(prop) > 2 and prop[1] == 'Reference':
                val = prop[2]
                if isinstance(val, str) and val.startswith('LED'):
                    ref = val
                    break

    if not ref:
        return None

    # Get position
    at_node = sexpr_find_one(node, 'at')
    if not at_node or len(at_node) < 3:
        return None

    try:
        sym_x = float(at_node[1])
        sym_y = float(at_node[2])
        rotation = float(at_node[3]) if len(at_node) > 3 else 0.0
    except (ValueError, IndexError):
        return None

    # Check for mirror
    mirror_y = False
    for item in node:
        if isinstance(item, list) and sexpr_tag(item) == 'mirror' and len(item) > 1:
            mirror_y = item[1] == 'y'
        elif item == 'mirror':
            # Sometimes mirror is followed by 'y' as next sibling
            pass
    # Also check for bare 'mirror' with 'y' — KiCad sometimes uses:
    # (mirror y) as a standalone child
    for i, item in enumerate(node):
        if isinstance(item, list) and len(item) == 2 and item[0] == 'mirror':
            mirror_y = item[1] == 'y'

    uuid = ''
    uuid_node = sexpr_find_one(node, 'uuid')
    if uuid_node and len(uuid_node) > 1:
        uuid = uuid_node[1]

    # Determine pin definitions
    di_def, do_def = PIN_DEFS[pin_key]

    # Compute absolute pin positions
    di_pos = transform_pin(sym_x, sym_y, di_def.x, di_def.y, mirror_y, rotation)
    do_pos = transform_pin(sym_x, sym_y, do_def.x, do_def.y, mirror_y, rotation)

    led = LedSymbol(
        ref=ref,
        lib_id=lib_id,
        package=package,
        uuid=uuid,
        x=sym_x,
        y=sym_y,
        mirror_y=mirror_y,
        rotation=rotation,
        di_pin=di_pos,
        do_pin=do_pos,
    )
    return led


def _parse_wire(node: list) -> Optional[Wire]:
    """Parse a wire node."""
    pts_node = sexpr_find_one(node, 'pts')
    if not pts_node:
        return None

    xy_nodes = sexpr_find(pts_node, 'xy')
    if len(xy_nodes) < 2:
        return None

    try:
        x1 = float(xy_nodes[0][1])
        y1 = float(xy_nodes[0][2])
        x2 = float(xy_nodes[1][1])
        y2 = float(xy_nodes[1][2])
    except (ValueError, IndexError):
        return None

    return Wire(x1, y1, x2, y2)


# ---------------------------------------------------------------------------
# Net tracing — Union-Find for connecting wire endpoints and pin positions
# ---------------------------------------------------------------------------

TOLERANCE = 0.01  # mm — KiCad coordinates are in mm with high precision


def snap_coord(val: float) -> float:
    """Snap coordinate to grid to handle floating point comparison."""
    return round(val, 2)


def coord_key(x: float, y: float) -> tuple[float, float]:
    """Create a hashable coordinate key."""
    return (snap_coord(x), snap_coord(y))


class UnionFind:
    """Union-Find data structure for net connectivity."""

    def __init__(self):
        self.parent: dict = {}
        self.rank: dict = {}

    def find(self, x):
        if x not in self.parent:
            self.parent[x] = x
            self.rank[x] = 0
        if self.parent[x] != x:
            self.parent[x] = self.find(self.parent[x])
        return self.parent[x]

    def union(self, a, b):
        ra, rb = self.find(a), self.find(b)
        if ra == rb:
            return
        if self.rank[ra] < self.rank[rb]:
            ra, rb = rb, ra
        self.parent[rb] = ra
        if self.rank[ra] == self.rank[rb]:
            self.rank[ra] += 1


def build_net_connectivity(leds: list[LedSymbol], wires: list[Wire]) -> dict[str, str]:
    """
    Build net connectivity and return a mapping: DO_ref -> DI_ref.

    This tells us: the DO pin of LED X connects to the DI pin of LED Y,
    meaning X comes before Y in the chain.
    """
    uf = UnionFind()

    # Register all wire endpoints and connect them
    for wire in wires:
        k1 = coord_key(wire.x1, wire.y1)
        k2 = coord_key(wire.x2, wire.y2)
        uf.find(k1)
        uf.find(k2)
        uf.union(k1, k2)

    # Map each net (by root) to the pins connected to it
    # pin_type: 'do' or 'di', with the LED ref
    net_pins: dict[tuple, list[tuple[str, str]]] = {}  # root -> [(ref, 'do'|'di'), ...]

    for led in leds:
        do_key = coord_key(*led.do_pin)
        di_key = coord_key(*led.di_pin)

        # Ensure pin positions are in the UF (they may not touch a wire if
        # they are at a wire endpoint — they should be, but let's be safe)
        uf.find(do_key)
        uf.find(di_key)

        # Connect pin to wires at same position (already handled by UF if
        # the pin coordinate matches a wire endpoint)
        do_root = uf.find(do_key)
        di_root = uf.find(di_key)

        net_pins.setdefault(do_root, []).append((led.ref, 'do'))
        net_pins.setdefault(di_root, []).append((led.ref, 'di'))

    # Build DO→DI connections
    # For each net, if it contains exactly one DO and one DI from different LEDs,
    # that's a chain link.
    do_to_di: dict[str, str] = {}  # ref_from -> ref_to

    for root, pins in net_pins.items():
        do_refs = [ref for ref, ptype in pins if ptype == 'do']
        di_refs = [ref for ref, ptype in pins if ptype == 'di']

        if len(do_refs) == 1 and len(di_refs) == 1:
            from_ref = do_refs[0]
            to_ref = di_refs[0]
            if from_ref != to_ref:  # sanity check
                do_to_di[from_ref] = to_ref
        elif len(do_refs) > 1 or len(di_refs) > 1:
            # Multiple DOs or DIs on same net — unusual, log it
            print(f"  WARNING: Net at root {root} has {len(do_refs)} DO "
                  f"and {len(di_refs)} DI pins: DO={do_refs}, DI={di_refs}",
                  file=sys.stderr)

    return do_to_di


def find_chain_start(leds: list[LedSymbol], do_to_di: dict[str, str],
                     wires: list[Wire], global_label: Optional[str]) -> Optional[str]:
    """
    Find the first LED in the chain — the one whose DI pin is connected to
    the chain's data input (global label / sheet pin) rather than another LED's DO.

    The start LED is the one that appears as a DI target but never as a DO source's target,
    i.e., no other LED's DO connects to its DI.
    """
    # All refs that are targets of a DO connection (i.e. their DI is fed by some LED's DO)
    fed_by_led = set(do_to_di.values())

    # All LED refs
    all_refs = {led.ref for led in leds}

    # Start candidates: LEDs whose DI is NOT fed by another LED's DO
    candidates = all_refs - fed_by_led

    if len(candidates) == 1:
        return candidates.pop()
    elif len(candidates) == 0:
        print(f"  ERROR: No chain start found (circular chain?)", file=sys.stderr)
        return None
    else:
        # Multiple candidates — try to disambiguate
        # This can happen if the sub-sheet has multiple chain segments
        # (e.g., rail_w feeds into rail_w_southbound)
        print(f"  INFO: Multiple chain start candidates: {sorted(candidates)}",
              file=sys.stderr)
        # Return the one with the lowest LED number as a heuristic
        return sorted(candidates, key=lambda r: int(re.search(r'\d+', r).group()))[0]


def walk_chain(start_ref: str, do_to_di: dict[str, str]) -> list[str]:
    """Walk the chain from start, following DO→DI links. Returns ordered list of refs."""
    chain = [start_ref]
    current = start_ref
    visited = {start_ref}

    while current in do_to_di:
        next_ref = do_to_di[current]
        if next_ref in visited:
            print(f"  ERROR: Cycle detected at {current} -> {next_ref}", file=sys.stderr)
            break
        chain.append(next_ref)
        visited.add(next_ref)
        current = next_ref

    return chain


# ---------------------------------------------------------------------------
# Multi-sheet chain handling
# ---------------------------------------------------------------------------

# Map sub-sheet filenames to chain names and expected LED counts
CHAIN_SHEETS = {
    'rail_w': {
        'chain': 'rail_w',
        'sub_sheets': ['rail_w.kicad_sch', 'rail_w_southbound.kicad_sch'],
        'expected_count': 106,
    },
    'rail_e': {
        'chain': 'rail_e',
        'sub_sheets': ['rail_e.kicad_sch'],
        'expected_count': 48,
    },
    'ferries_n': {
        'chain': 'ferries_n',
        'sub_sheets': ['ferries_n.kicad_sch'],
        'expected_count': 46,
    },
    'ferries_s': {
        'chain': 'ferries_s',
        'sub_sheets': ['ferries_s.kicad_sch'],
        'expected_count': 47,
    },
}


def process_chain(chain_name: str, config: dict, project_dir: Path) -> dict:
    """
    Process all sub-sheets for a chain and return the ordered LED list.

    For multi-sheet chains (rail_w + rail_w_southbound), the sheets are
    concatenated: the last LED's DO in sheet 1 connects to the first LED's
    DI in sheet 2 via an inter-sheet label.
    """
    print(f"\n{'='*60}")
    print(f"Processing chain: {chain_name}")
    print(f"{'='*60}")

    all_segments = []

    for sheet_name in config['sub_sheets']:
        sheet_path = project_dir / sheet_name
        if not sheet_path.exists():
            print(f"  WARNING: Sheet {sheet_name} not found, skipping", file=sys.stderr)
            continue

        print(f"\n  Parsing {sheet_name}...")
        leds, wires, global_label = parse_schematic(sheet_path)

        print(f"  Found {len(leds)} LEDs, {len(wires)} wires")
        if global_label:
            print(f"  Global label: '{global_label}'")

        # Print LED details for debugging
        for led in sorted(leds, key=lambda l: int(re.search(r'\d+', l.ref).group())):
            print(f"    {led.ref}: ({led.x}, {led.y}) mirror_y={led.mirror_y} "
                  f"pkg={led.package} DO={led.do_pin} DI={led.di_pin}")

        # Build connectivity
        do_to_di = build_net_connectivity(leds, wires)
        print(f"  DO→DI connections found: {len(do_to_di)}")
        for from_ref, to_ref in sorted(do_to_di.items(),
                                         key=lambda x: int(re.search(r'\d+', x[0]).group())):
            print(f"    {from_ref} → {to_ref}")

        # Find chain start and walk
        start = find_chain_start(leds, do_to_di, wires, global_label)
        if start:
            print(f"  Chain start: {start}")
            ordered = walk_chain(start, do_to_di)
            print(f"  Chain order ({len(ordered)} LEDs): {' → '.join(ordered)}")

            # Build segment data
            led_lookup = {led.ref: led for led in leds}
            segment = []
            for ref in ordered:
                led = led_lookup[ref]
                segment.append({
                    'ref': ref,
                    'package': led.package,
                    'schematic_x': led.x,
                    'schematic_y': led.y,
                })
            all_segments.append({
                'sheet': sheet_name,
                'leds': segment,
            })
        else:
            print(f"  ERROR: Could not determine chain start for {sheet_name}")

    # Concatenate segments for multi-sheet chains
    full_chain = []
    for seg in all_segments:
        full_chain.extend(seg['leds'])

    expected = config['expected_count']
    actual = len(full_chain)
    status = "OK" if actual == expected else f"MISMATCH (expected {expected})"
    print(f"\n  Total LEDs in {chain_name}: {actual} — {status}")

    if actual != expected:
        print(f"  WARNING: Expected {expected} LEDs but found {actual}",
              file=sys.stderr)

    return {
        'chain': chain_name,
        'expected_count': expected,
        'actual_count': actual,
        'segments': [s['sheet'] for s in all_segments],
        'leds': full_chain,
    }


# ---------------------------------------------------------------------------
# Main
# ---------------------------------------------------------------------------
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

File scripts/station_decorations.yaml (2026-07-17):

defaults:
  layer: F.SilkS
  snap_mm: 0.25
  generated_group_prefix: 'stationgen:'
  lock_generated_items: true
styles:
  standard:
    decoration:
      kind: none
    label:
      style: plain
      align: auto
      vertical_align: center
      side: E
      offset_mm: 0.8
      anchor_radius_mm: 1.8
      size_mm: 1.2
      stroke_mm: 0.15
      angle_deg: 0
  ferry_port:
    decoration:
      kind: none
    label:
      style: plain
      align: auto
      vertical_align: center
      side: E
      offset_mm: 0.8
      anchor_radius_mm: 2.7
      size_mm: 1.2
      stroke_mm: 0.15
      angle_deg: 0
  transfer:
    decoration:
      kind: rounded_rect
      padding_mm: 0.7
      content_radius_mm: 1.3
      stroke_mm: 0.1
      radius_mm: 0.4
      angle_deg: 0
    label:
      style: plain
      align: auto
      vertical_align: center
      side: E
      offset_mm: 1.0
      size_mm: 1.2
      stroke_mm: 0.15
      angle_deg: 0
  terminal:
    decoration:
      kind: none
    label:
      style: knockout
      align: center
      vertical_align: center
      side: S
      offset_mm: 1.0
      size_mm: 1.3
      stroke_mm: 0.1625
      angle_deg: 0
      pill_padding_x_mm: 0.6
      pill_padding_y_mm: 0.35
      pill_radius_mm: 0.4
stations:
  mukilteo:
    class: transfer
    refs: [LED1101, LED1409, LED1416]
    label:
      text: Mukilteo
      side: N
      align: left
      align_x: left
      offset_mm: 0.8
  edmonds:
    class: transfer
    refs: [LED1015, LED1406, LED1419]
    label:
      text: Edmonds
      side: N
      align: left
      align_x: left
      offset_mm: 0.8
  king_street:
    class: transfer
    refs: [LED1401, LED1424, LED1527, LED1627]
    label:
      text: King Street
      side: W
  seattle:
    class: transfer
    refs: [LED514, LED701]
    label:
      text: Seattle
      side: N
      align: right
    sublabels:
      - text: Pier 52
        position_mm: [125.357, 53.0]
      - text: Pier 50
        position_mm: [125.357, 60.5]
  tacoma_dome:
    class: terminal
    refs: [LED1304, LED1305, LED1306, LED1333, LED1334, LED1335]
    label:
      text: Tacoma Dome
      align: left
      vertical_align: bottom
      position_mm: [126.25242, 202.55713]
      angle_deg: 315
  intl_district_chinatown:
    class: standard
    refs: [LED1527, LED1627]
    label:
      text: |-
        Intl. District
        Chinatown
      side: E
      align: left
      offset_mm: 1.4
  st_joseph:
    class: terminal
    refs: [LED1801, LED1824]
    label:
      text: St Joseph
      side: SW
      align: auto
  hilltop_district:
    class: standard
    refs: [LED1802, LED1823]
    label:
      text: Hilltop District
      side: SE
      align: center
      angle_deg: 315.0
  star_lake:
    class: standard
    refs: [LED1503, LED1651]
    label:
      text: Star Lake
      side: E
      align: left
  6th_ave:
    class: standard
    refs: [LED1803, LED1822]
    label:
      text: 6th Ave
      side: SE
      align: center
      angle_deg: 315.0
  tacoma_general:
    class: standard
    refs: [LED1804, LED1821]
    label:
      text: Tacoma General
      side: SE
      align: center
      angle_deg: 315.0
  stadium_district:
    class: standard
    refs: [LED1805, LED1820]
    label:
      text: Stadium District
      side: SE
      align: center
      angle_deg: 315.0
  s_4th_st:
    class: standard
    refs: [LED1806, LED1819]
    label:
      text: S 4th St
      side: SE
      align: center
      angle_deg: 315.0
  old_city_hall:
    class: standard
    refs: [LED1807, LED1818]
    label:
      text: Old City Hall
      side: SE
      align: center
      angle_deg: 315.0
  theater_district:
    class: standard
    refs: [LED1808, LED1817]
    label:
      text: Theater District
      side: N
      align: left
      align_x: left
      angle_deg: 45.0
      cross_align: top
  led1508:
    class: standard
    refs: [LED1808, LED1817]
  convention_center:
    class: standard
    refs: [LED1809, LED1816]
    label:
      text: Convention Center
      side: NE
      align: center
      angle_deg: 45.0
  union_station:
    class: standard
    refs: [LED1810, LED1815]
    label:
      text: Union Station
      side: NE
      align: center
      angle_deg: 45.0
  s_25th_st:
    class: standard
    refs: [LED1811, LED1814]
    label:
      text: S 25th St
      side: NE
      align: left
      angle_deg: 45.0
  lakewood:
    class: terminal
    refs: [LED1301, LED1338]
    label:
      text: Lakewood
      side: W
      align: auto
  south_tacoma:
    class: standard
    refs: [LED1303, LED1336]
    label:
      text: South Tacoma
      side: SE
      align: auto
      angle_deg: 315.0
  puyallup:
    class: standard
    refs: [LED1308, LED1331]
    label:
      text: Puyallup
      side: S
      align: left
      align_x: left
      angle_deg: 315.0
  sumner:
    class: standard
    refs: [LED1310, LED1329]
    label:
      text: Sumner
      side: E
      align: left
  auburn:
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

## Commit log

2026-03-13 hello world
    [ferries_n.kicad_sch, ferries_s.kicad_sch, rail_e.kicad_sch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]
2026-03-16 PCBA prototype order
    [ferries_n.kicad_sch, ferries_s.kicad_sch, rail_e.kicad_sch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]
2026-04-10 Add images, stub README
    [transit.kicad_pcb, transit_stop_leds.csv]
2026-05-20 Rev B component layout
    [ferries.kicad_sch, ferries_n.kicad_sch, ferries_s.kicad_sch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]
2026-05-21 Add basemap, rerouting checkpoint
    [transit.kicad_sch]
2026-05-23 Sounder and T silk, before scripting
    [ferries.kicad_sch, ferries_n.kicad_sch, ferries_s.kicad_sch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]
2026-05-23 layout water taxi
    [fauntleroy_vashon_southworth.kicad_sch, ferries.kicad_sch, ferries_s.kicad_sch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]
2026-05-24 sounder layout checkpoint
    [edmonds_kingston.kicad_sch, ferries.kicad_sch, ferries_n.kicad_sch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]
2026-05-24 initial layout checkpoint
    [rail.kicad_sch, sounder_n.kicad_sch, sounder_s.kicad_sch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]
2026-05-26 pier 50 routing checkpoint
    [fauntleroy_vashon_southworth.kicad_sch, rail.kicad_sch, seattle_southworth.kicad_sch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]
2026-05-27 checkpoint before stopping double routing
    [seattle_bremerton.kicad_sch]
2026-05-27 single ferry track checkpoint
    [edmonds_kingston.kicad_sch, fauntleroy_vashon_southworth.kicad_sch, port_defiance_tahlequah.kicad_sch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]
2026-05-28 checkpoint before label plugin
    [edmonds_kingston.kicad_sch, mukilteo_clinton.kicad_sch, seattle_bremerton.kicad_sch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]
2026-05-28 Initial LED placement complete
    [sounder_n.kicad_sch]
2026-05-29 Add rail labels
    [edmonds_kingston.kicad_sch, fauntleroy_vashon_southworth.kicad_sch, ferries_n.kicad_sch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]
2026-05-29 more room for sounder_s and monorail, label fixes
    [station_decorations.yaml]
2026-06-25 Route main circuit
    [transit.kicad_sch]
2026-06-25 route T
    [ferries.kicad_sch, ferries_n.kicad_sch, rail.kicad_sch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]
2026-06-25 Renumber Sounder, ready to route
    [sounder_n.kicad_sch, sounder_s.kicad_sch]
2026-06-26 route link 1
    [rail.kicad_sch, rail_e.kicad_sch, rail_w.kicad_sch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]
2026-06-26 route link 2
    [rail_e.kicad_sch]
2026-06-26 route monorail
    [ferries_n.kicad_sch, sounder_n.kicad_sch]
2026-06-26 Rail routed, add rectangle to Seattle port
2026-06-26 Route point defiance tahlequah
    [port_defiance_tahlequah.kicad_sch, transit.kicad_sch]
2026-06-28 junction checkpoint
    [fauntleroy_vashon_southworth.kicad_sch, port_defiance_tahlequah.kicad_sch, seattle_bainbridge.kicad_sch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]
2026-06-28 routing complete
    [edmonds_kingston.kicad_sch, fauntleroy_vashon_southworth.kicad_sch, mukilteo_clinton.kicad_sch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]
2026-06-28 reflow reference designators
    [edmonds_kingston.kicad_sch, seattle_bainbridge.kicad_sch, seattle_bremerton.kicad_sch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]
2026-06-30 rev-b validation run
    [edmonds_kingston.kicad_sch, fauntleroy_vashon_southworth.kicad_sch, ferries_n.kicad_sch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]
2026-07-16 Update R values to dim indicator LEDs
    [transit.kicad_sch]
2026-07-16 Remove test points, slight shift bremerton LEDs, cleanup around ALS
    [transit.kicad_sch]
2026-07-17 Replace ferry port LED
    [edmonds_kingston.kicad_sch, fauntleroy_vashon_southworth.kicad_sch, mukilteo_clinton.kicad_sch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]
2026-07-17 fix indicator led orientation
    [transit.kicad_sch]
2026-07-25 Update BOM, remove VLED bulk capacitors, add Rev C to silkscreen
    [rail.kicad_sch, transit.kicad_sch]
2026-07-25 Update silkscreen, remove tp8, fix stale tp values
    [edmonds_kingston.kicad_sch, fauntleroy_vashon_southworth.kicad_sch, mukilteo_clinton.kicad_sch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]
2026-07-25 Update README, fix typos
    [ferries.kicad_sch, point_defiance_tahlequah.kicad_sch, transit.kicad_sch]

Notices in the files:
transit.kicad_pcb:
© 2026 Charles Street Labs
